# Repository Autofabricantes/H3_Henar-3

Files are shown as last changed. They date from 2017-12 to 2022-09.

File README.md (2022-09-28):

Hi! Welcome to the **_Henar#3 Wiki_**, please read carefully this welcome page that describes the full content of the _Wiki_.

This repository is still under construction (after many months, I know :'( ) Please if whatever doubt you have is not yet solved contact us somehow (email, Github, etc)

# Project Scope
The **_Henar#3_** is a _Open Source_ MIDI percussion instrument designed to perform live. Its main characteristics are:
* **Open Source:** The **_Henar#3_** has been designed and build with **_Open Source_** HW and SW and using accesible manufacturing technologies in order for it to be very affordable and easily moded.
* **Build Flexibility:** The **_Henar#3_** has been designed to allow a large number of different configurations (HMI elements in order to cope with the specific necessities of each user.
* **Stand Alone:** The **_Henar#3_** is an instrument designed to be played live, therefore it is a _Plug&Play_ device which does not need of extra elements to be played.
* **Pheriperic Flexibility:** Besides being a _Plug&Play_ device, the **_Henar#3_** allows its connection with other sound devices such as speakers and alternative MIDI devices.

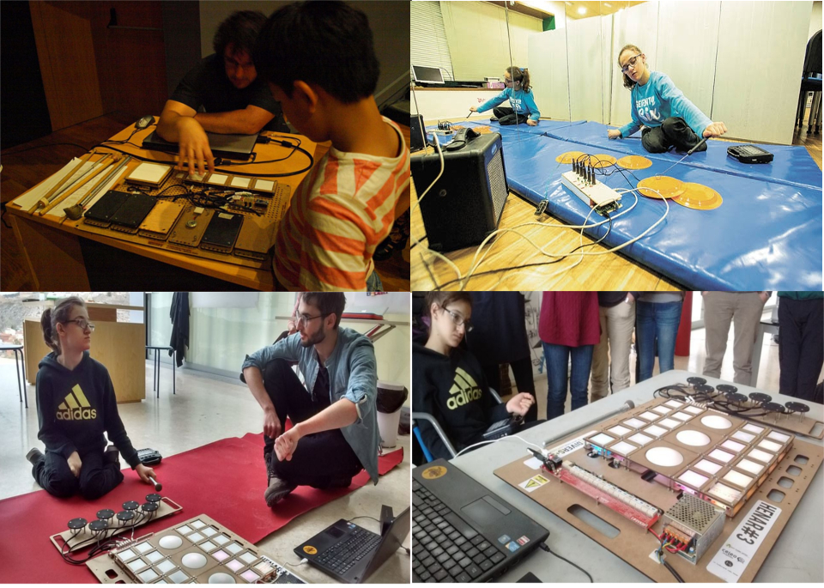
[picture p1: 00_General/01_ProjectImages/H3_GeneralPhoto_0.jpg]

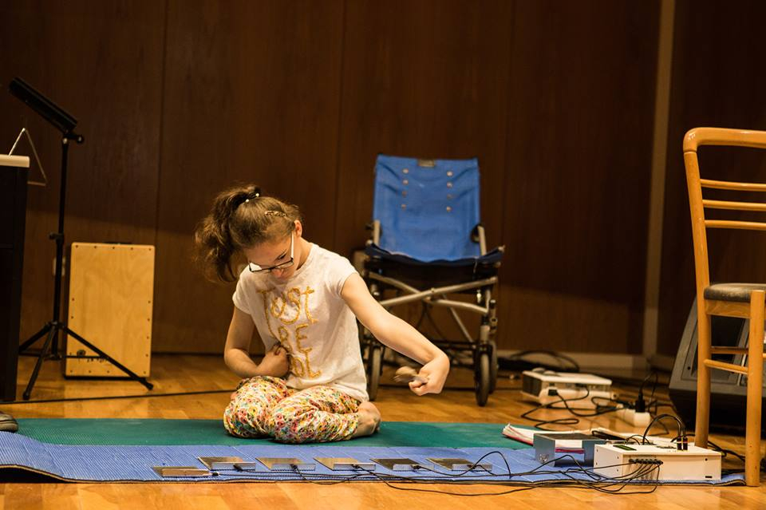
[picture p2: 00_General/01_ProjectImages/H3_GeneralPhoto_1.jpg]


# History and Collaborators
The **_Henar#3_** is part of a longer project started by the **_Celeo Proyectos_** and **_Un Instrumento para Henar_** in 2015. Its initial objective is to build a proper adapted instrument for Henar, a woman from Cuenca (Spain) that plays in an orchestra.

Apart from the instrument (which has two previous versions which will be described later) the project aims to build up a platform for the community of developers, users and enthusiasts to work together towards new ways to socialize with music and make it accesible for everyone. This is achieved not only though the development of the instrument itself but also through the creation of didactic materials and the organization of events such as **_DiverS+S 2017_** (http://www.diversos.eu/), where various projects were presented and put in common, in order to create links and an active net.

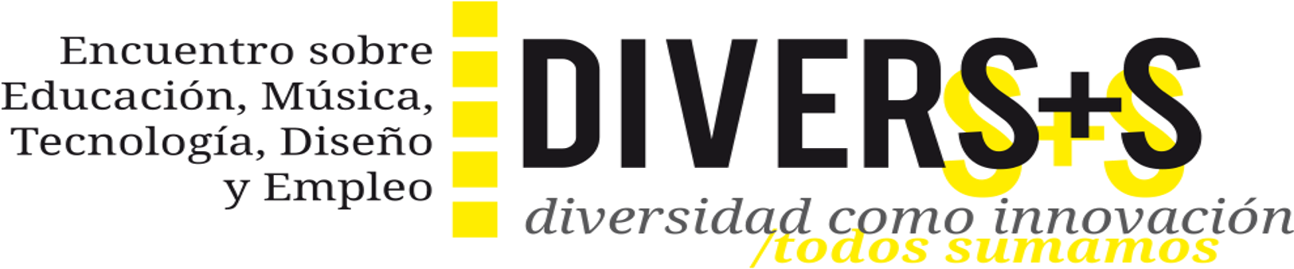
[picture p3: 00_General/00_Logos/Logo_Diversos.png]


The collaborators of this project are:
## Celeo Proyectos

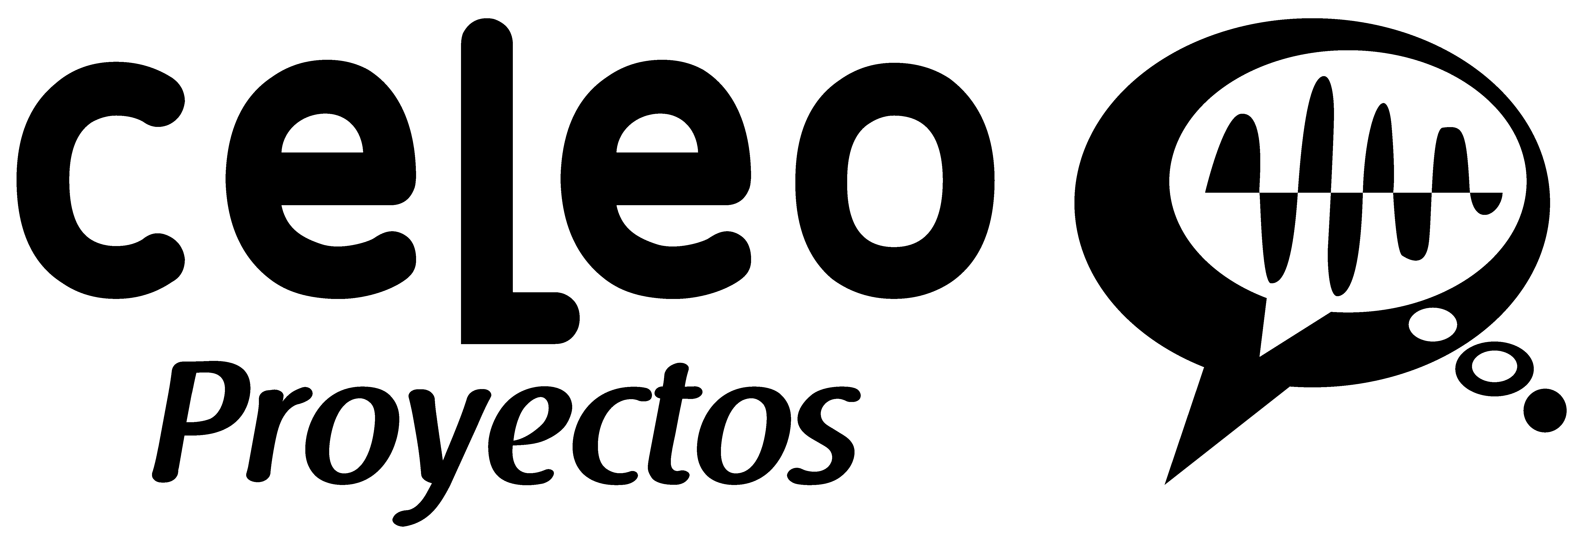
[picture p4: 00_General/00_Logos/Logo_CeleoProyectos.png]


## Un instrumento para Henar



### Website: www.centroceleo.es/henar
### Contact: uninstrumentoparahenar@gmail.com

## Autofabricantes
**_Autofabricantes_** in an association based in _Medialab-Prado_, Madrid. It develops several _Open Source_ technological solutions in the medical and accesibility field. It's main development lines right now are:
* Myoelectric Hand Prothesis for children.
* 3D printed hand prosthesis for children (both experimental like __SuperGizz__ and standard).
* **_Henar#3_** instrument (The one this Wiki covers).

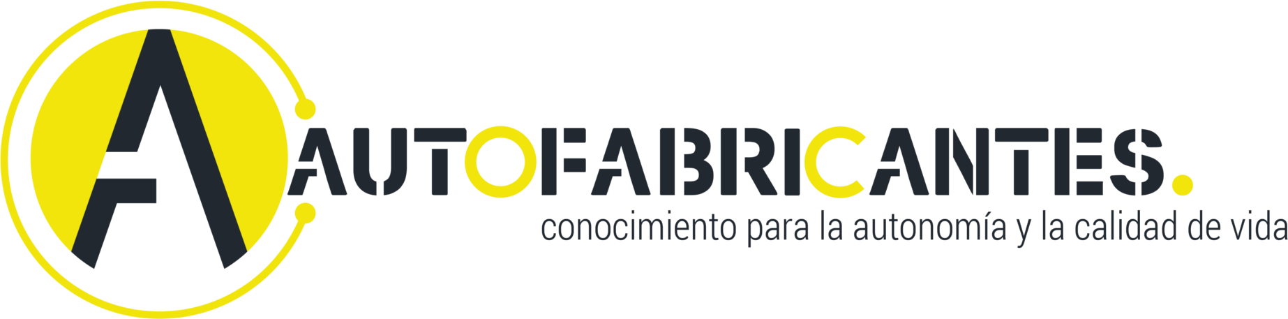
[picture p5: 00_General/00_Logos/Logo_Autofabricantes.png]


### Website: www.autofabricantes.org
### Contact: info@autofabricantes.org

## Escuela de Oficios Electrosonoros
_**Escuela de Oficios Electrosonoros**_ (in eng. _**School for Electrosonic Crafts**_) is an artistic and educational project that works to make electronic music (or music made with technology in general) accesible to everyone. 

*  Elaborate a feministic (or better just... diverse) history of electronic music.
*  Develop pedagogical tools for teaching electronic music in schools.
*  Research about accessibility of electronic music.

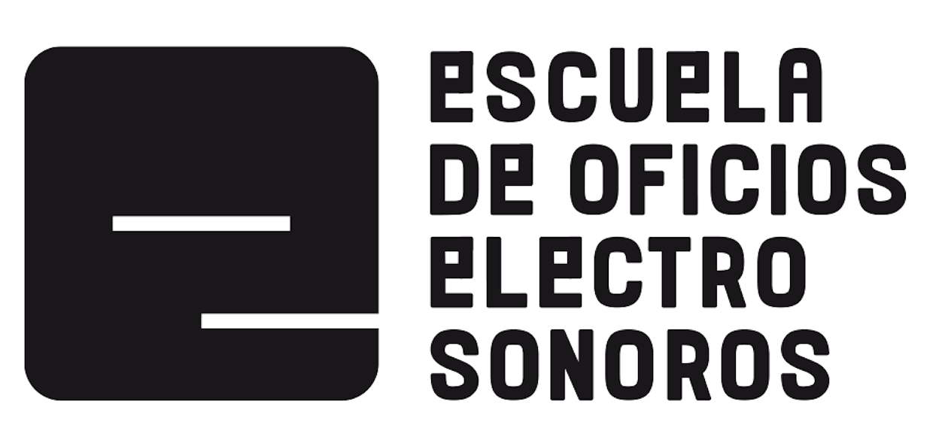
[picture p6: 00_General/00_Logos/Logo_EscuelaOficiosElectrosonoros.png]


### Website: www.oficioselectrosonoros.org
### Contact: gurrupibaby@gmail.com

# About the previous Henar (Henar#1, Henar#2)
The Un instrumento para Henar project has already developed two previous versions of the instruments.

## Henar#1: [HERE LINK]
## Henar#2: [HERE LINK]

The **_Henar#3_** improvement objetives are:
* Increase System flexibility.
* Easier Assembly and manufacturing.
* Easier MIDI configuration.
* Improved ergonomy.

# Scope of the Wiki
This _Wiki_ aims to concentrate all the knowledge of the project. This covers:
* Global description of the project and its subsystems.
* Description of all the files in the repository.
* Description of all the elements and their evolution.
* **Assembly Guide** of all the elements (HW, SW, Mechanical).
* Tutorials and other didactic material.

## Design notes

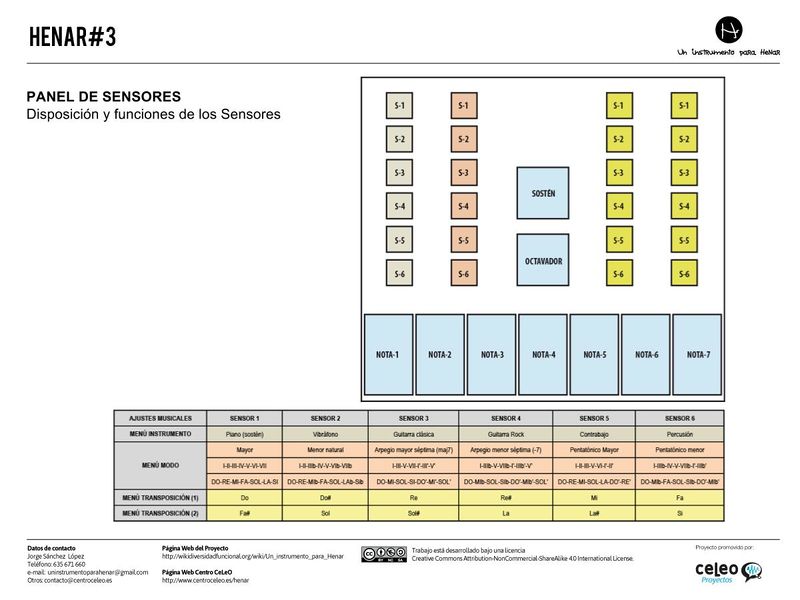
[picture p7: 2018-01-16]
01_Documentation/H3_ControlPanelProposal.jpg

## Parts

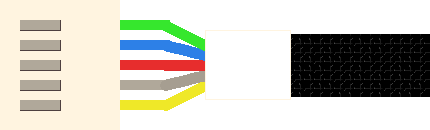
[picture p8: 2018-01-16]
03_Resources/H3_ComponentImages/H3_Wire_SWPad_Rev_1_2DRender_Simple.png

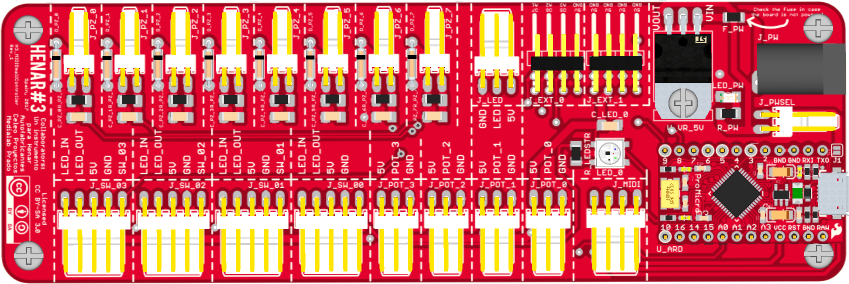
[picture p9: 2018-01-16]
03_Resources/H3_ComponentImages/H3_MIDISmallController_Rev_1_2DRender_A.png

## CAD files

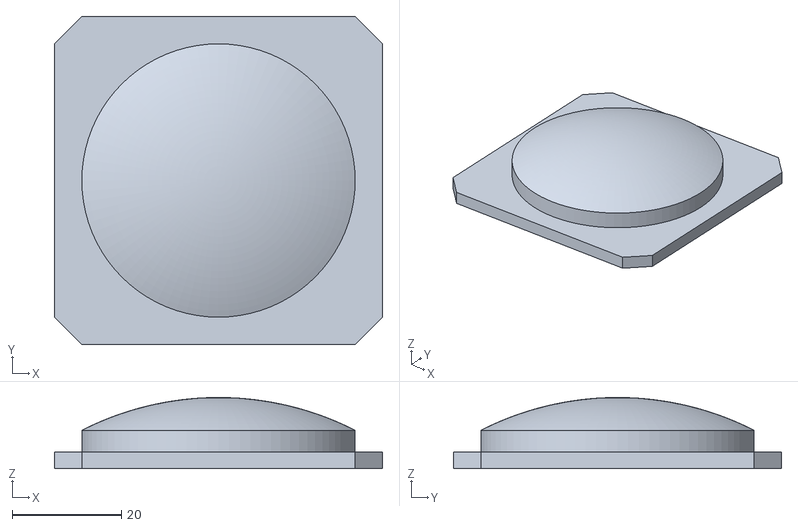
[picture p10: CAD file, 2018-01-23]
02_Elements/H3_SWPad_Big_Rev_3/03_Mechanics/H3_SWPad_Small_Rev_3_PadPiece_Circle.stl
60.0 x 60.0 x 13.0

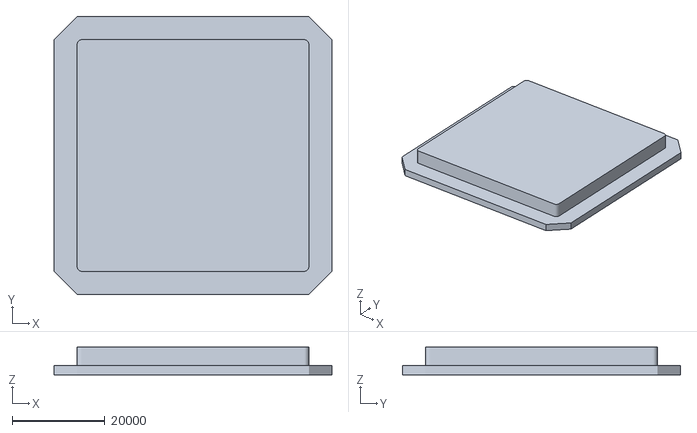
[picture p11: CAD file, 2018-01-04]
02_Elements/H3_SWPad_Small_Rev_3/01_HW/eagleUp/HW_SWPad_Small_Rev_3_PadPiece_A.stl
60000.0 x 60000.0 x 6000.0

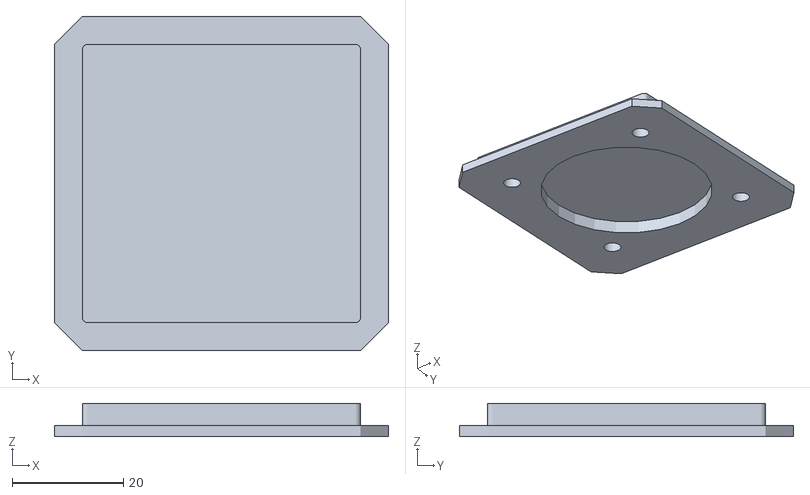
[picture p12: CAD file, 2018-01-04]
02_Elements/H3_SWPad_Big_Rev_3/03_Mechanics/H3_SWPad_Small_Rev_3_PadPiece_Square.stl
60.0 x 60.0 x 6.00

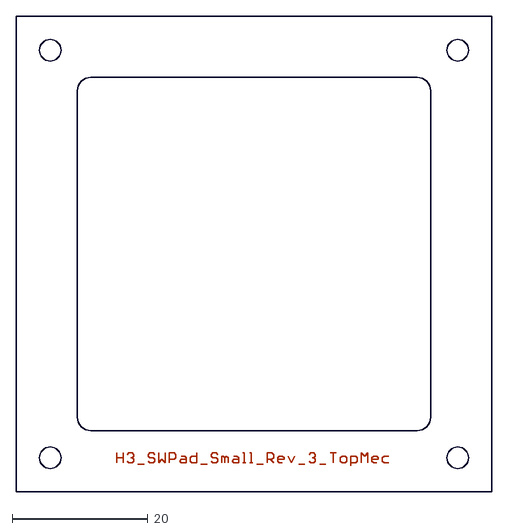
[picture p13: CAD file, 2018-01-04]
02_Elements/H3_SWPad_Big_Rev_3/03_Mechanics/H3_SWPad_Small_Rev_3_TopMec.dxf
70.0 x 70.0

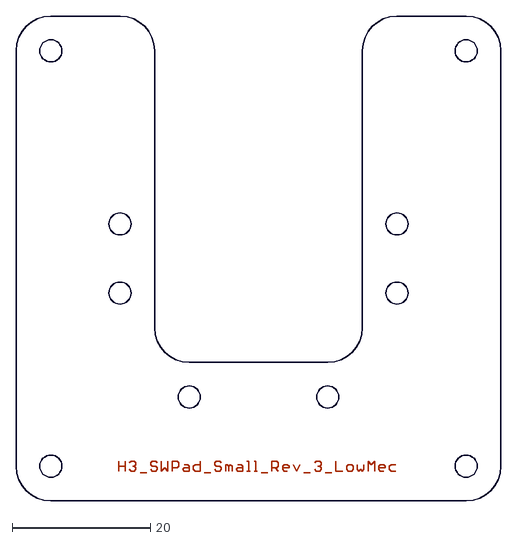
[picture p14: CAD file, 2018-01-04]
02_Elements/H3_SWPad_Big_Rev_3/03_Mechanics/H3_SWPad_Small_Rev_3_BotMec.dxf
70.0 x 70.0

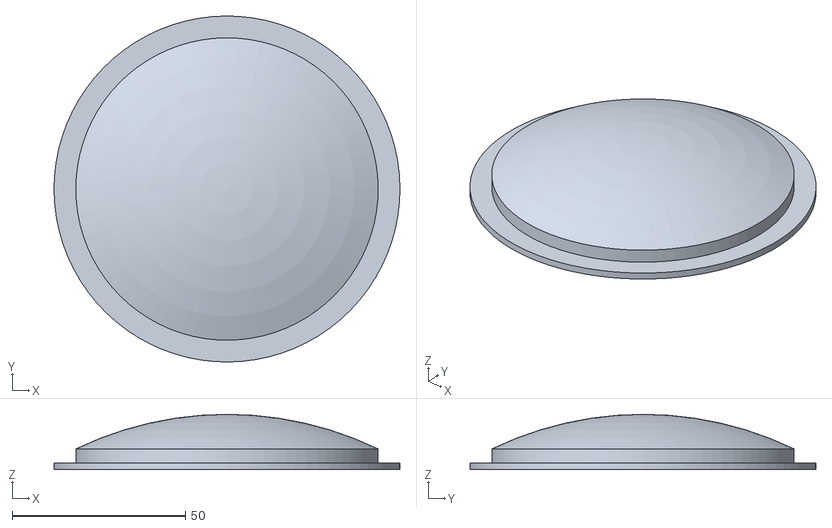
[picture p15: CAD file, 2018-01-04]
02_Elements/H3_SWPad_Big_Rev_3/03_Mechanics/H3_SWPad_Big_Rev_3_PadPiece_Circle.stl
100.0 x 100.0 x 16.0

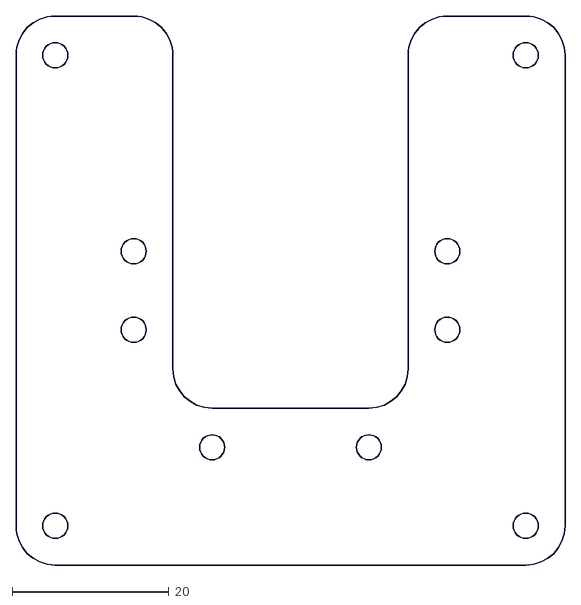
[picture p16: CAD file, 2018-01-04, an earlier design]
02_Elements/H3_SWPad_Small_Rev_2/03_Mechanics/H3_SWPad_Small_Rev_2_BotMec.dxf
70.0 x 70.0

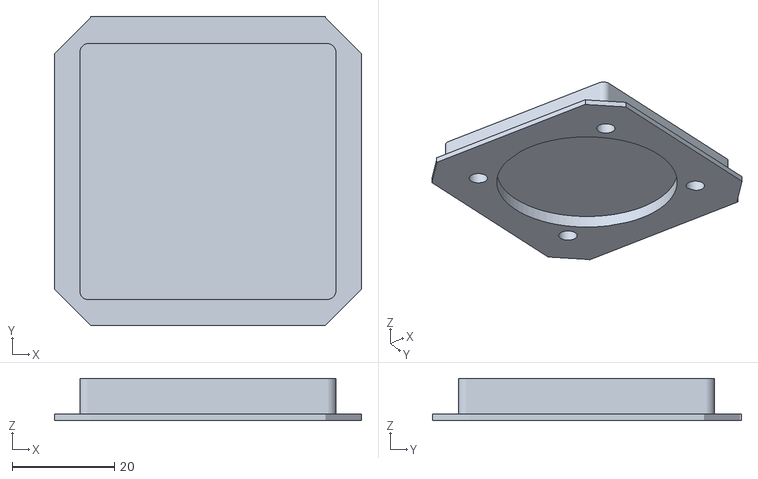
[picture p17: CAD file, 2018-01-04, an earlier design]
02_Elements/H3_SWPad_Small_Rev_2/03_Mechanics/H3_SWPad_Small_Rev_2_Pad_Square_Simple7mm.stl
60.0 x 60.4 x 8.30

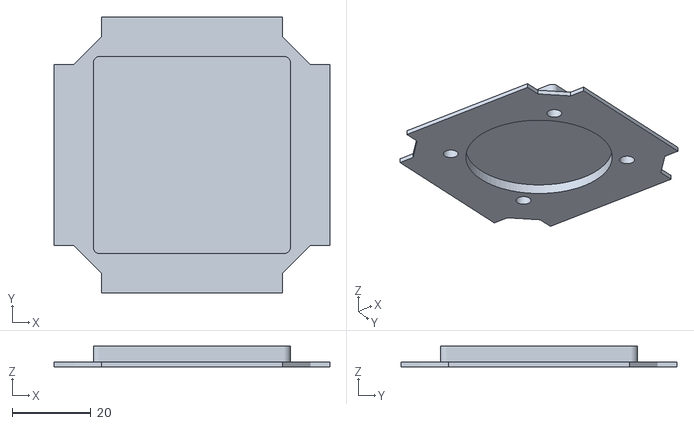
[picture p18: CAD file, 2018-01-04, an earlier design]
02_Elements/H3_SWPad_Small_Rev_2/03_Mechanics/H3_SWPad_Small_Rev_2_Pad_Square_Simple.stl
70.0 x 70.0 x 5.30

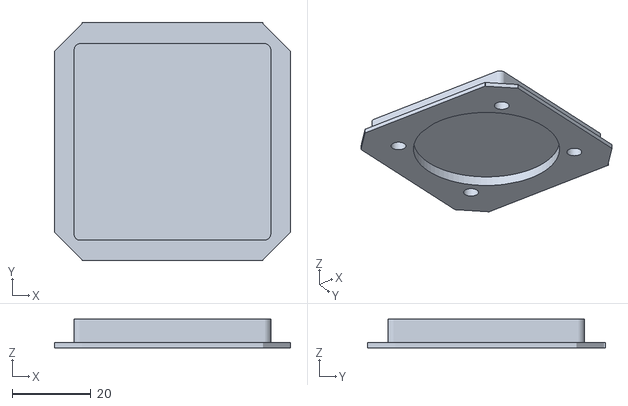
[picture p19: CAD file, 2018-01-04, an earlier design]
02_Elements/H3_SWPad_Small_Rev_2/03_Mechanics/H3_SWPad_Small_Rev_2_Pad_Square_Simple6mm.stl
60.0 x 60.4 x 7.30

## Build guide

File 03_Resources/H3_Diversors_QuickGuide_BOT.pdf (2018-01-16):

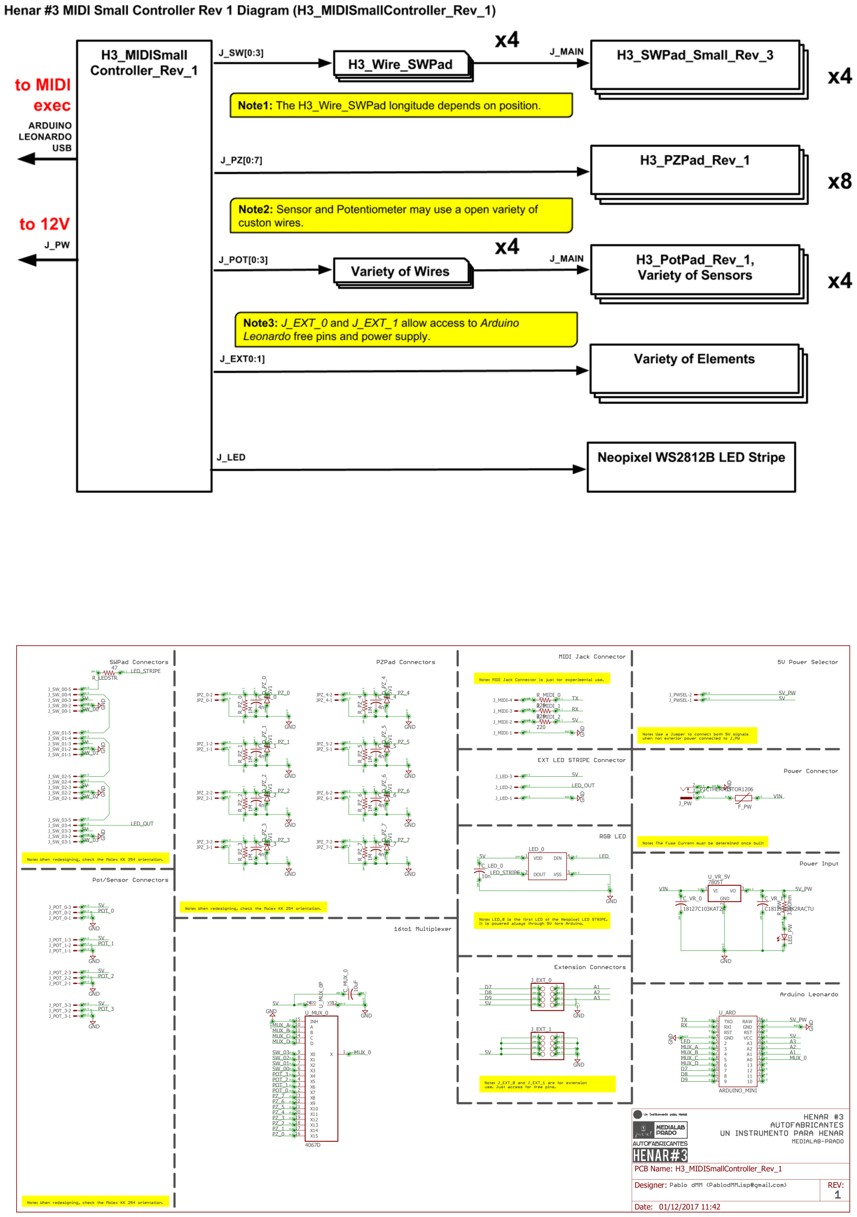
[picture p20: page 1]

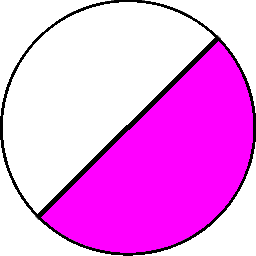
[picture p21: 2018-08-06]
01_Documentation/H3_GuideResources/H3_PAD_Render/H3_PAD_VSWAP_ON.png

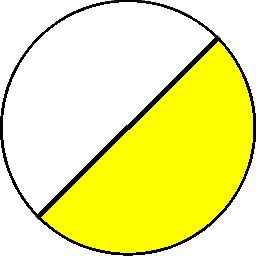
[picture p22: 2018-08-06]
01_Documentation/H3_GuideResources/H3_PAD_Render/H3_PAD_CHORD_ON.png

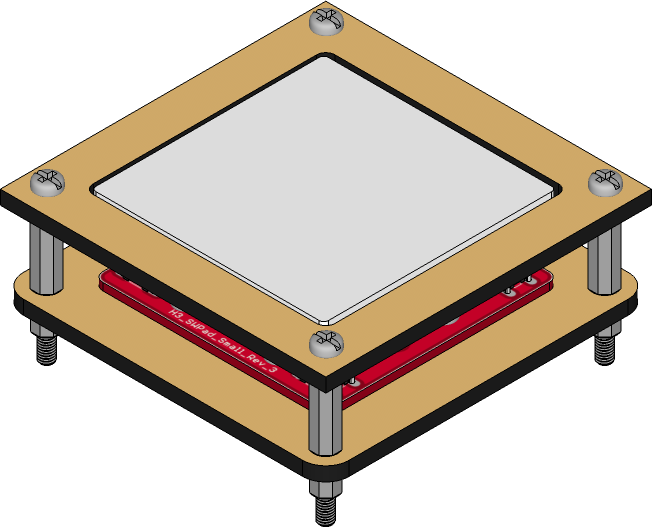
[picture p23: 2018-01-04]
02_Elements/H3_SWPad_Big_Rev_3/00_Documentation/H3_SWPad_Small_Rev_3_Assembled_2DRender.png

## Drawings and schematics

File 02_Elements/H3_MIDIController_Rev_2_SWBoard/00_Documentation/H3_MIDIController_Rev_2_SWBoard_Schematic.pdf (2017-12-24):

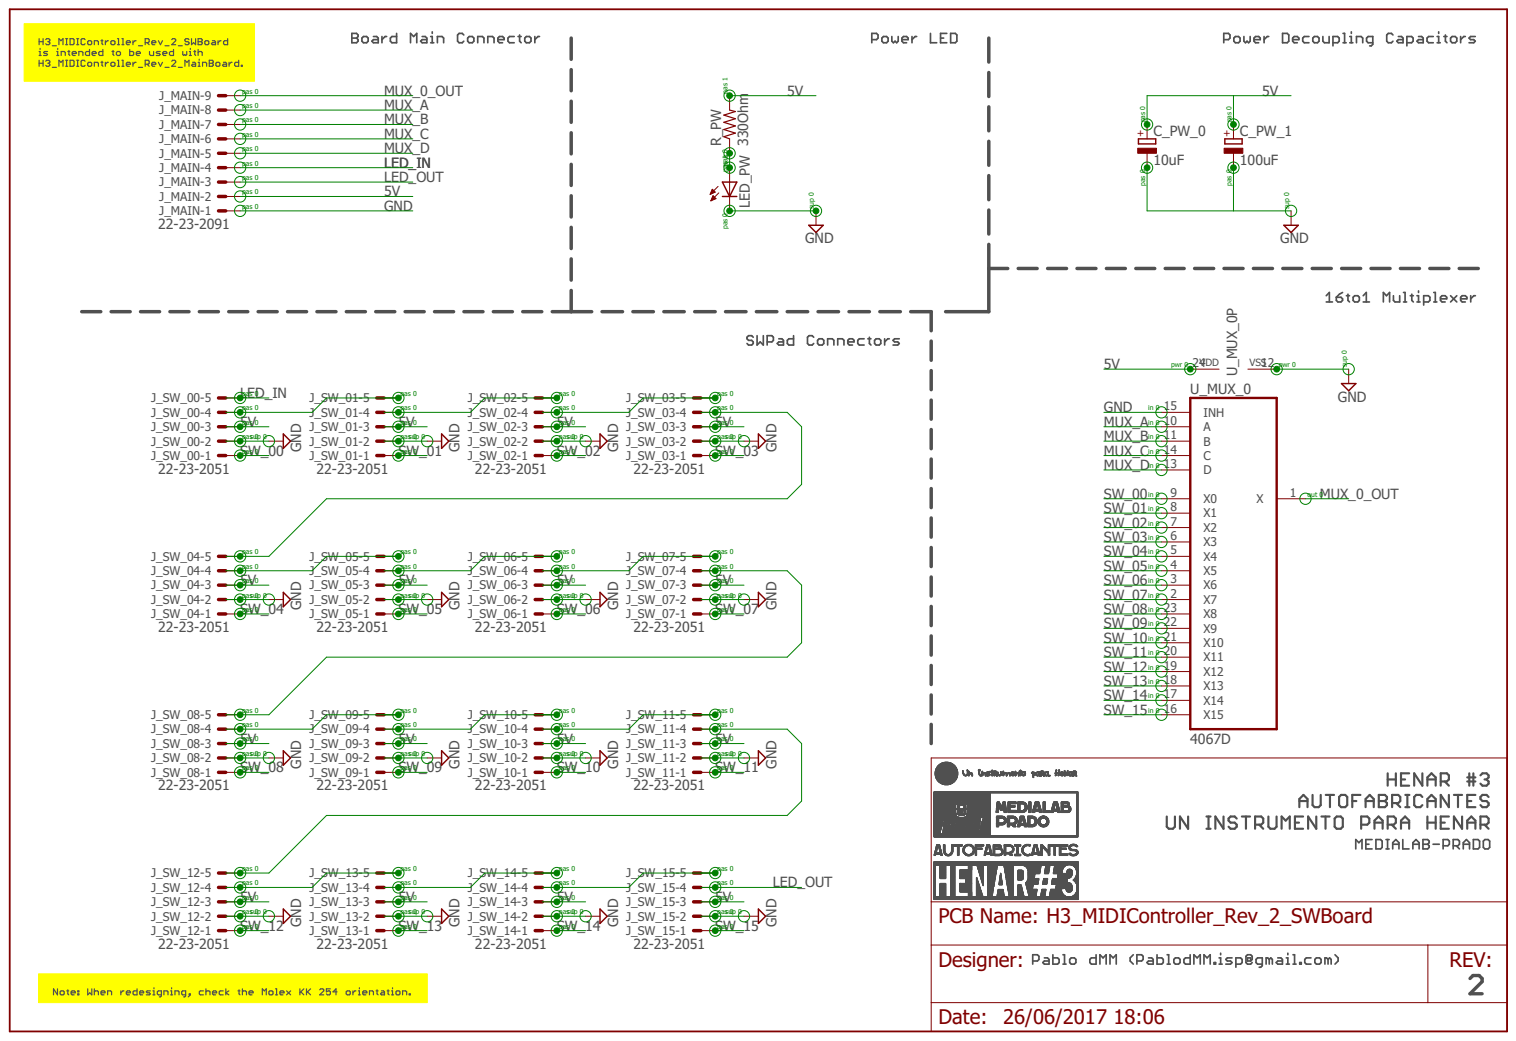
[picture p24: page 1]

pas 0 pas 0 pas 1 pas 1

pas 0 pas 0 pas 0 pas 0 pas 0 pas 0 pas 0 pas 0 pas 0

LED_IN
pas 0 pas 0 pas 0 pas 0 pas 0

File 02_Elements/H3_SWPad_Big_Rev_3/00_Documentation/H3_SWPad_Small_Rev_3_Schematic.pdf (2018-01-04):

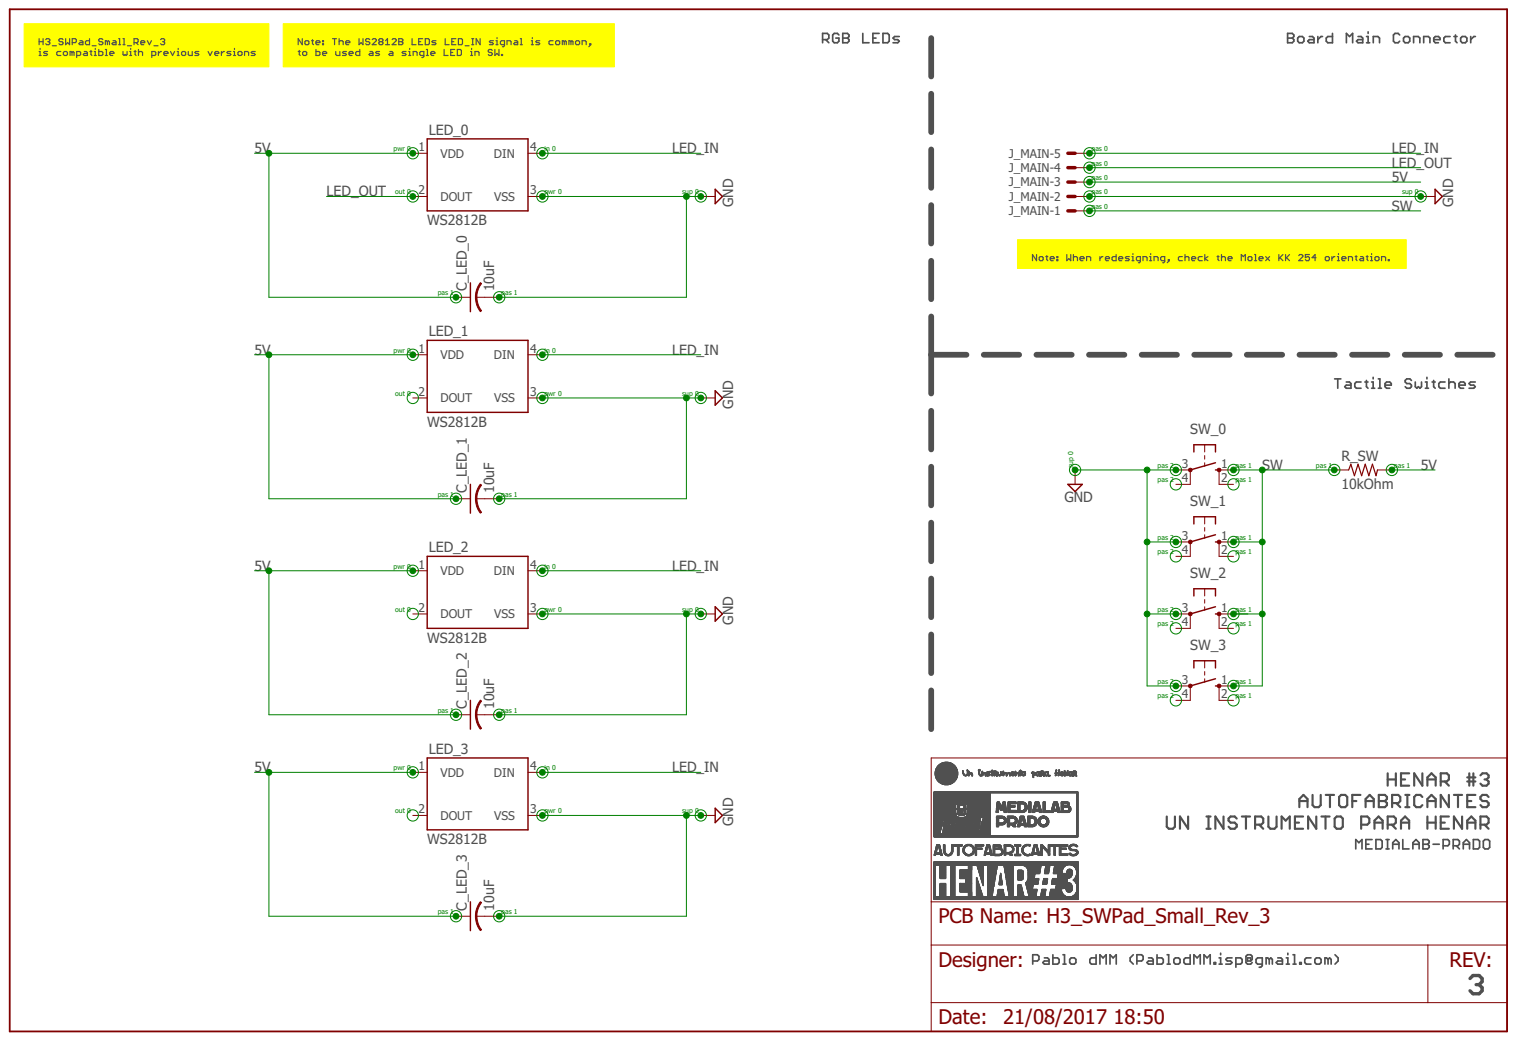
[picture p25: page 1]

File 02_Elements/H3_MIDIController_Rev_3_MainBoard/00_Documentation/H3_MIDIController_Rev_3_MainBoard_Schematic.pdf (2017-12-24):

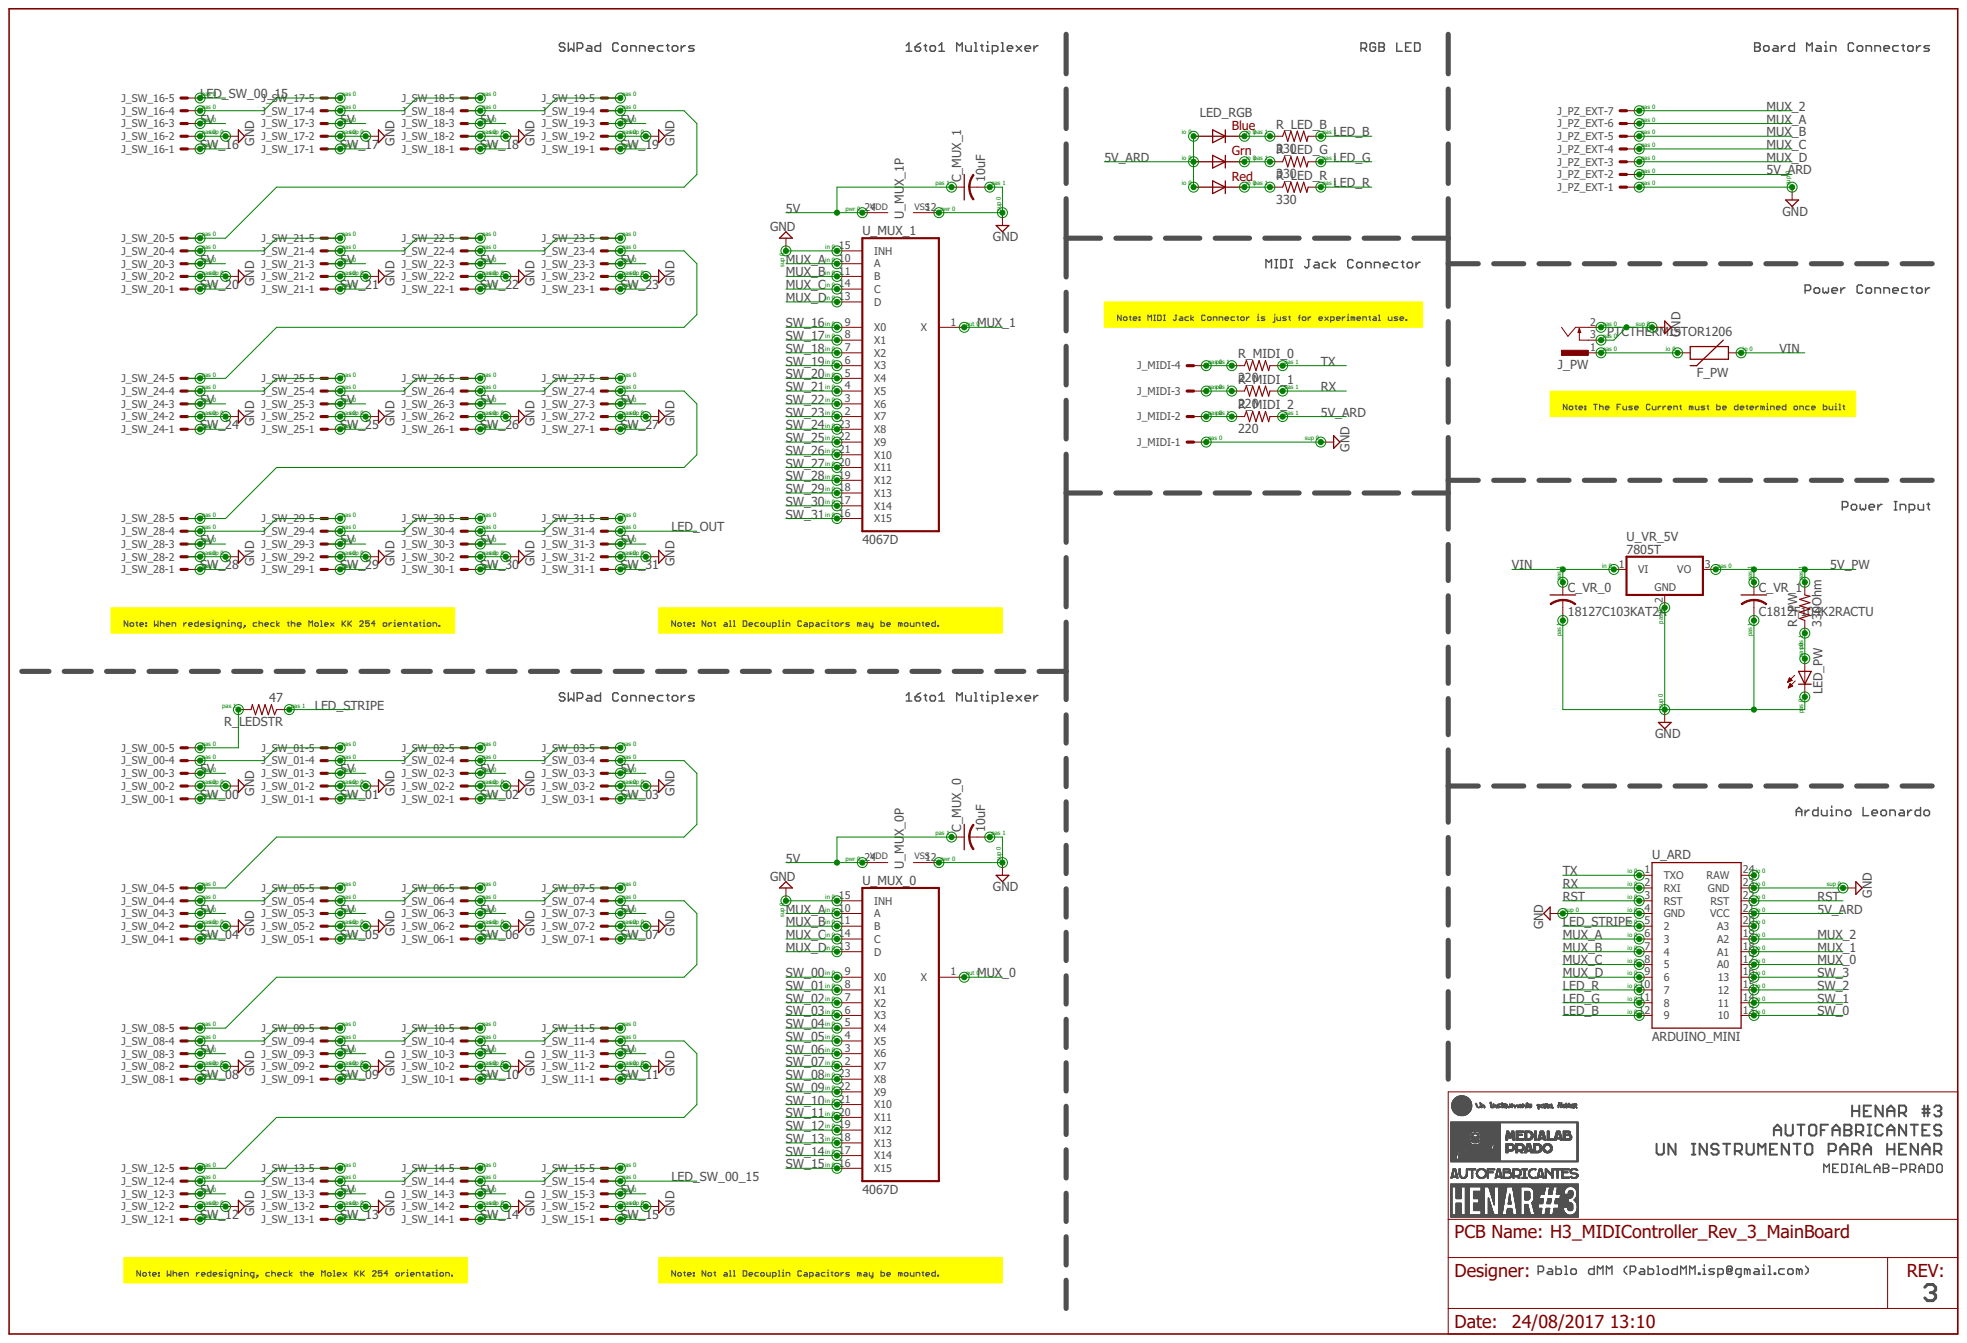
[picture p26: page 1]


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

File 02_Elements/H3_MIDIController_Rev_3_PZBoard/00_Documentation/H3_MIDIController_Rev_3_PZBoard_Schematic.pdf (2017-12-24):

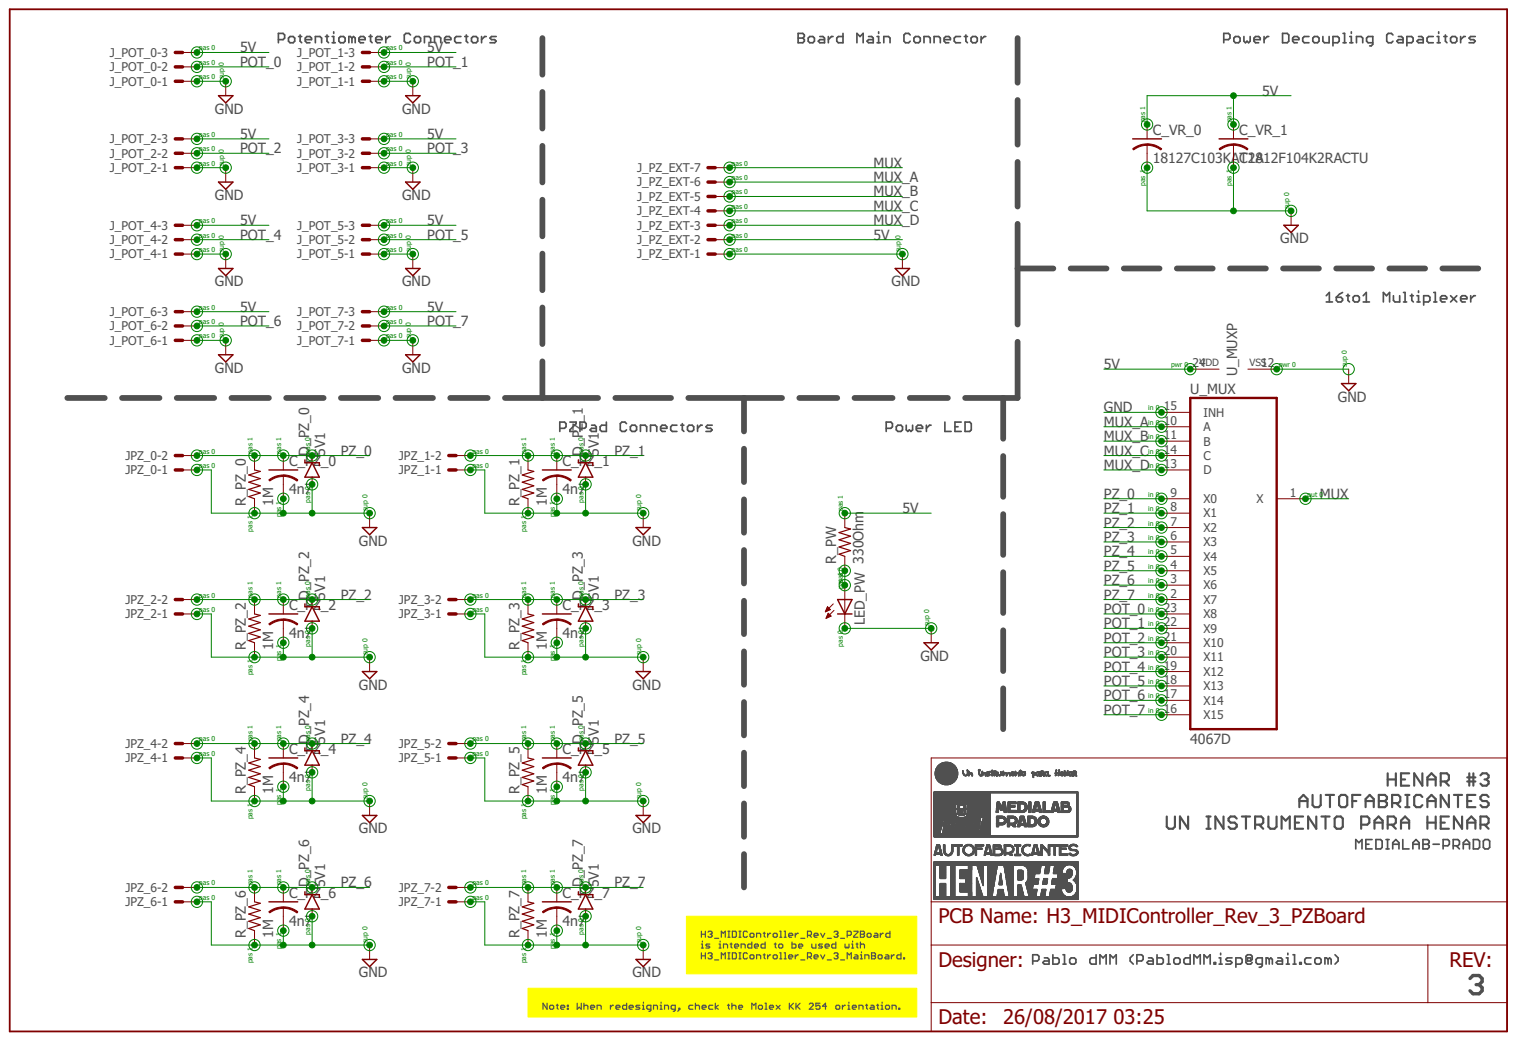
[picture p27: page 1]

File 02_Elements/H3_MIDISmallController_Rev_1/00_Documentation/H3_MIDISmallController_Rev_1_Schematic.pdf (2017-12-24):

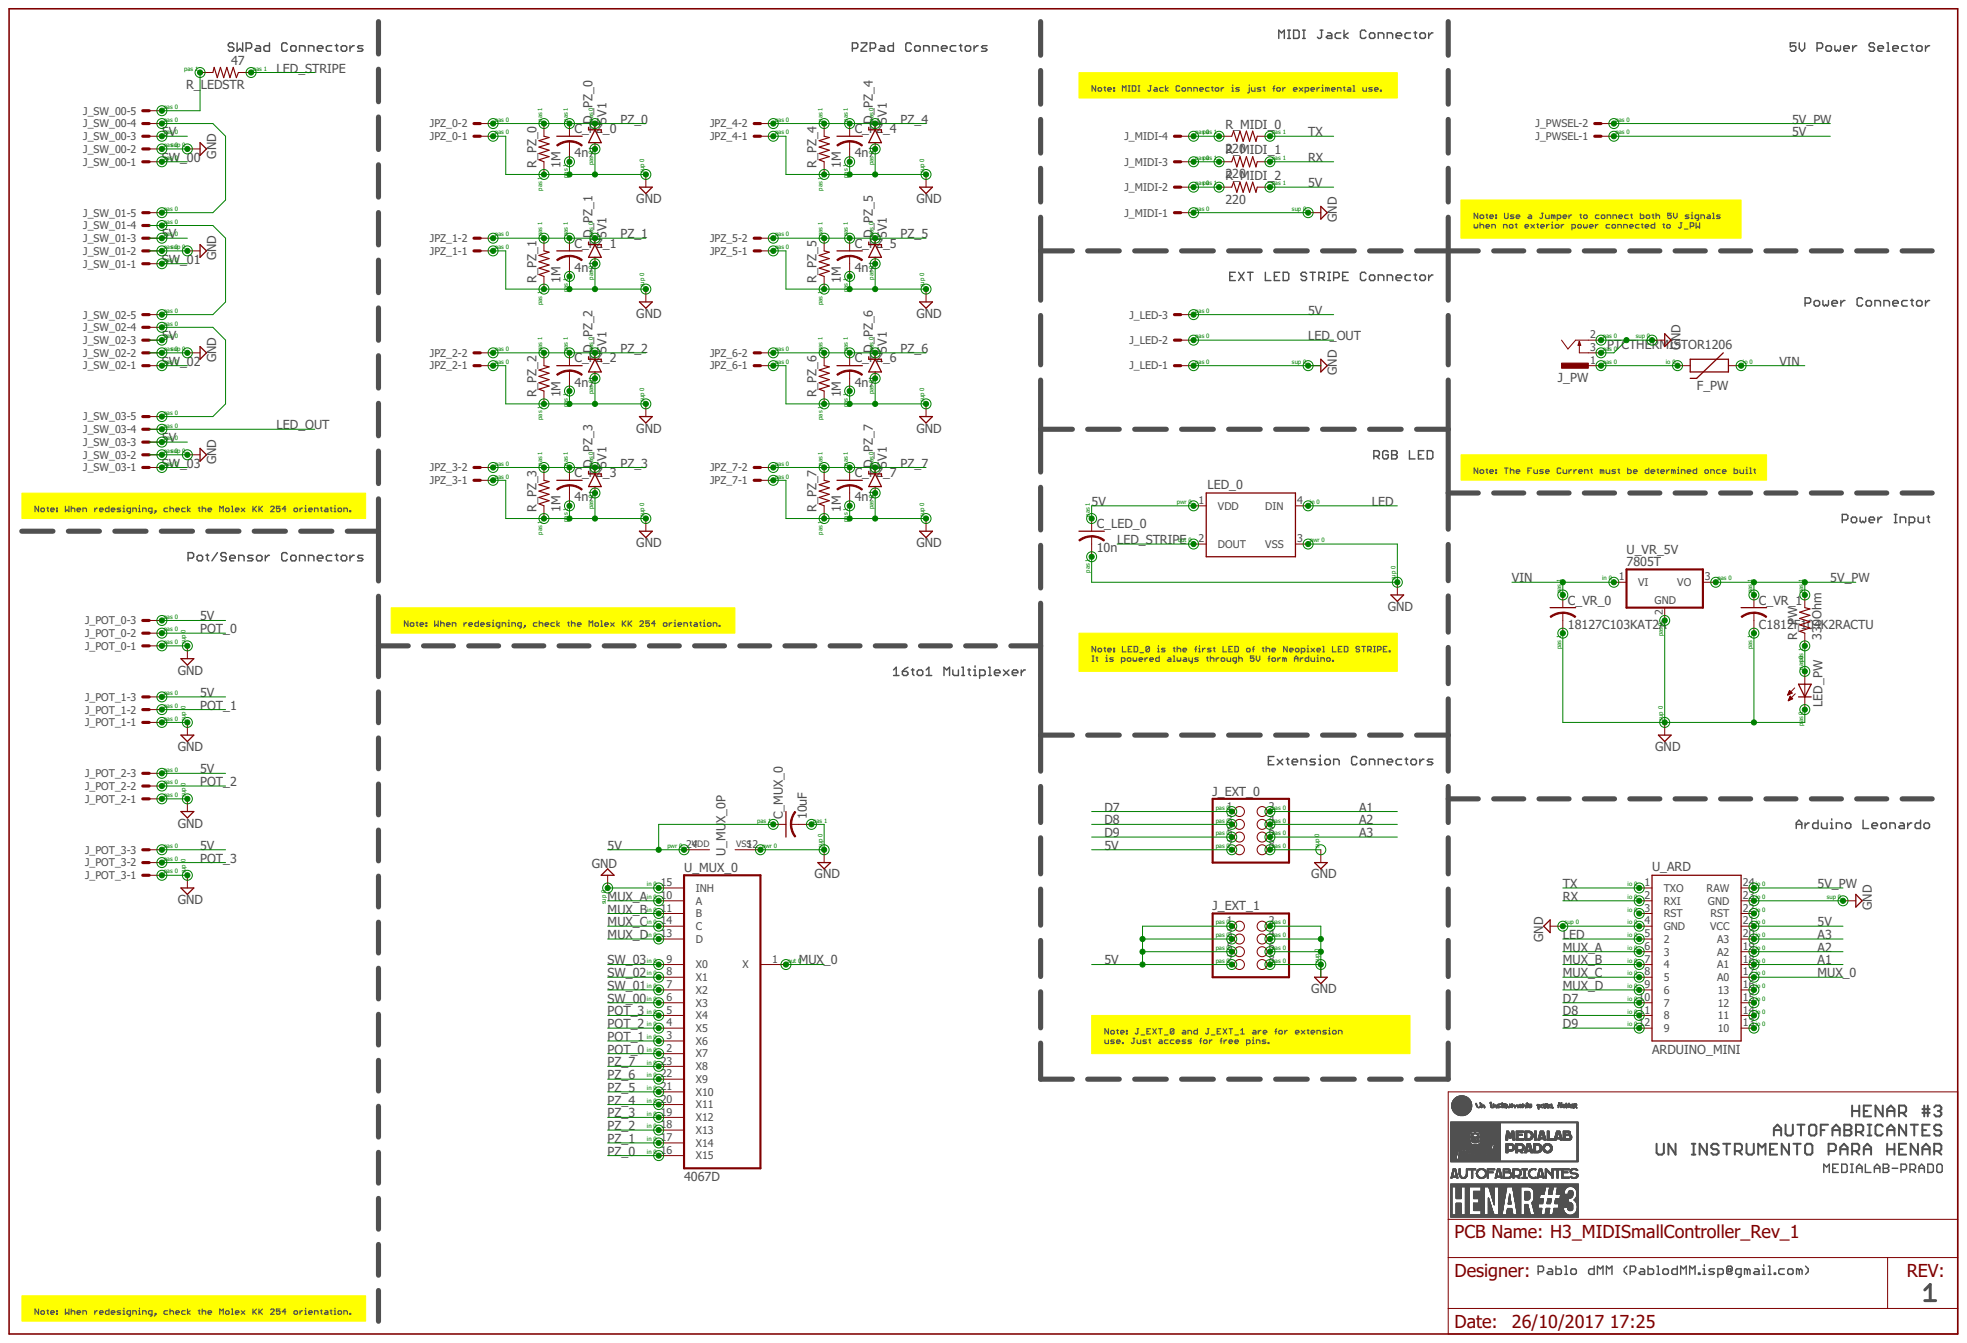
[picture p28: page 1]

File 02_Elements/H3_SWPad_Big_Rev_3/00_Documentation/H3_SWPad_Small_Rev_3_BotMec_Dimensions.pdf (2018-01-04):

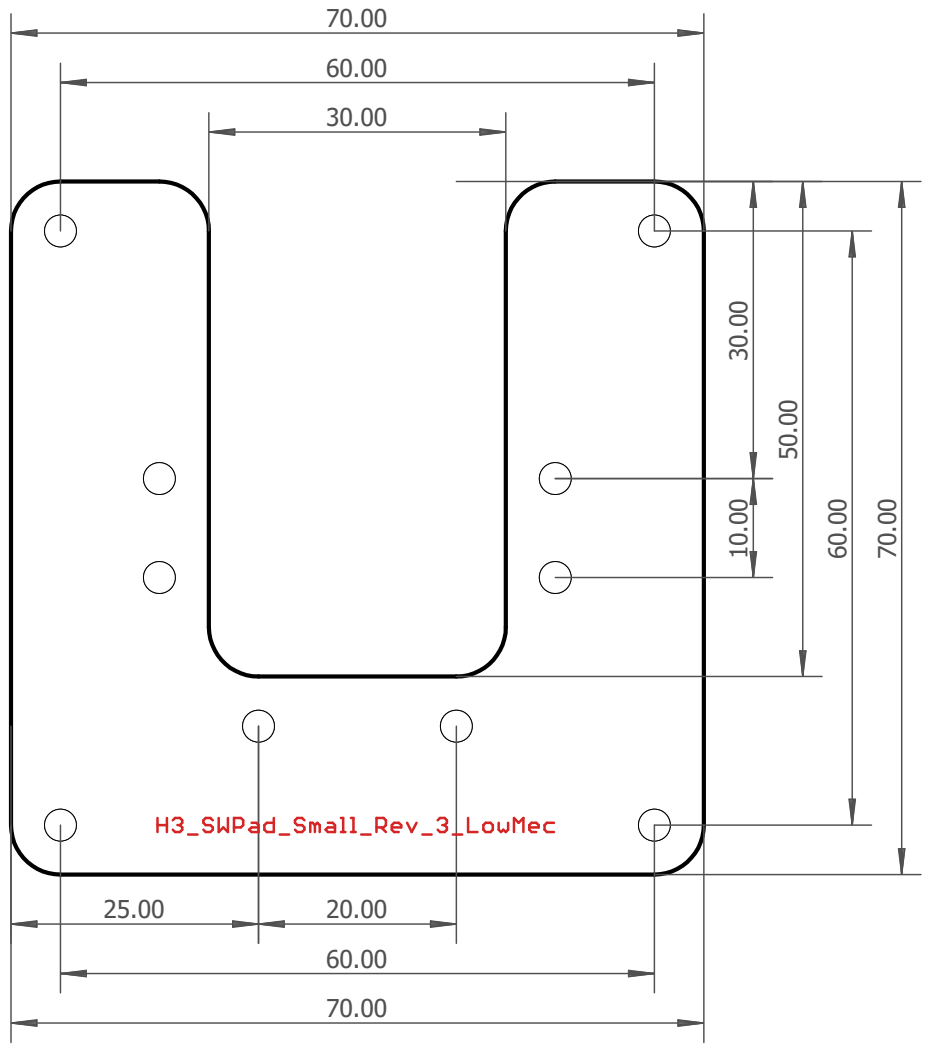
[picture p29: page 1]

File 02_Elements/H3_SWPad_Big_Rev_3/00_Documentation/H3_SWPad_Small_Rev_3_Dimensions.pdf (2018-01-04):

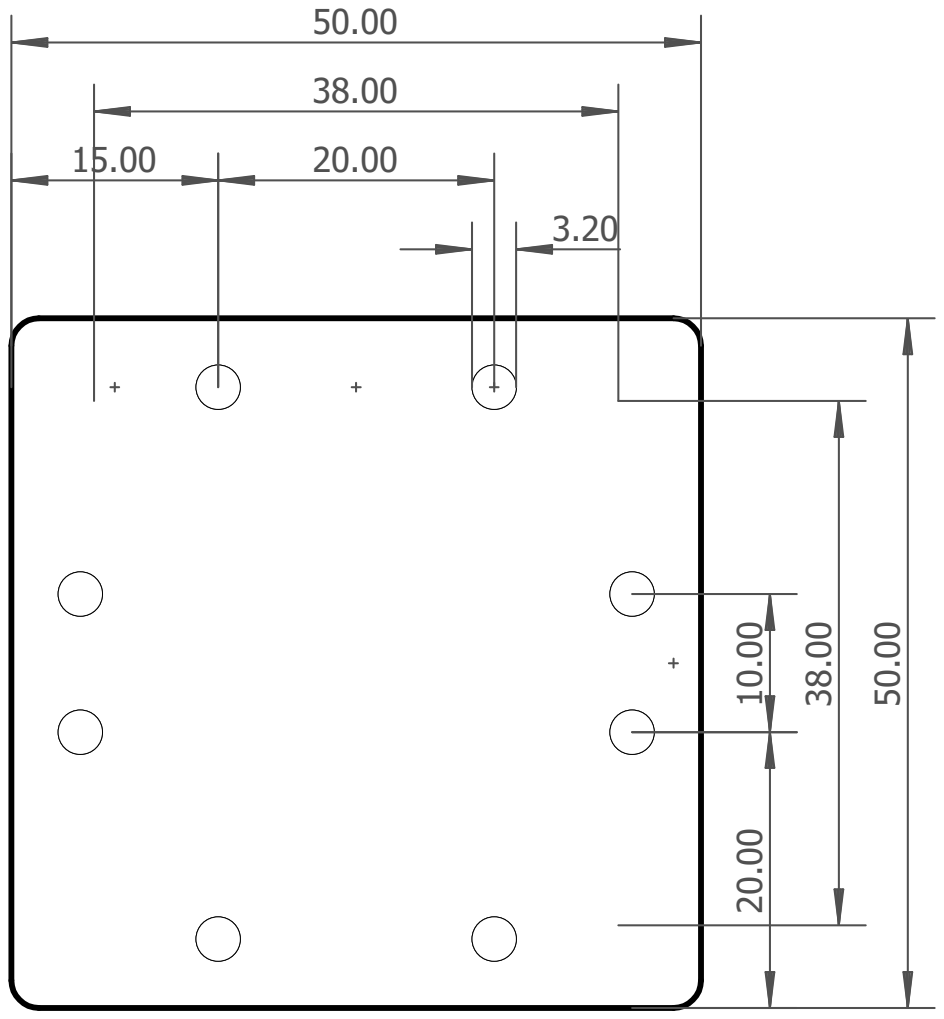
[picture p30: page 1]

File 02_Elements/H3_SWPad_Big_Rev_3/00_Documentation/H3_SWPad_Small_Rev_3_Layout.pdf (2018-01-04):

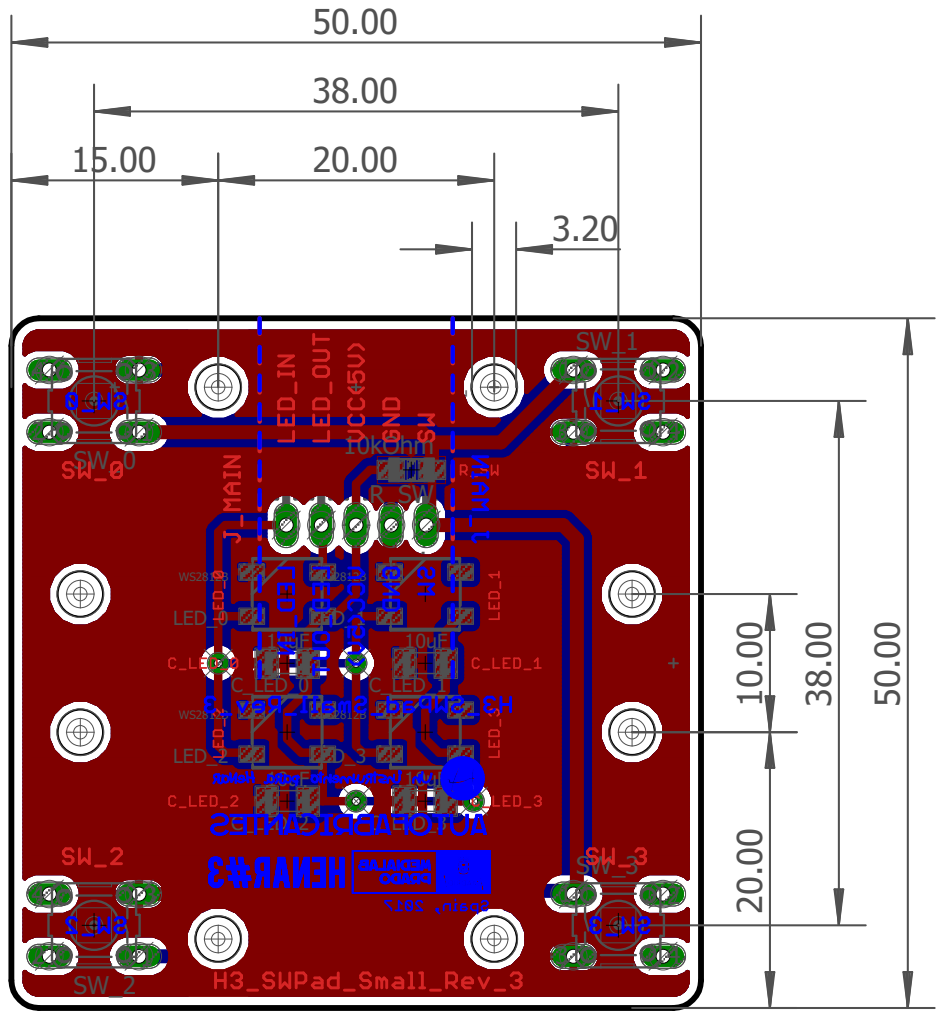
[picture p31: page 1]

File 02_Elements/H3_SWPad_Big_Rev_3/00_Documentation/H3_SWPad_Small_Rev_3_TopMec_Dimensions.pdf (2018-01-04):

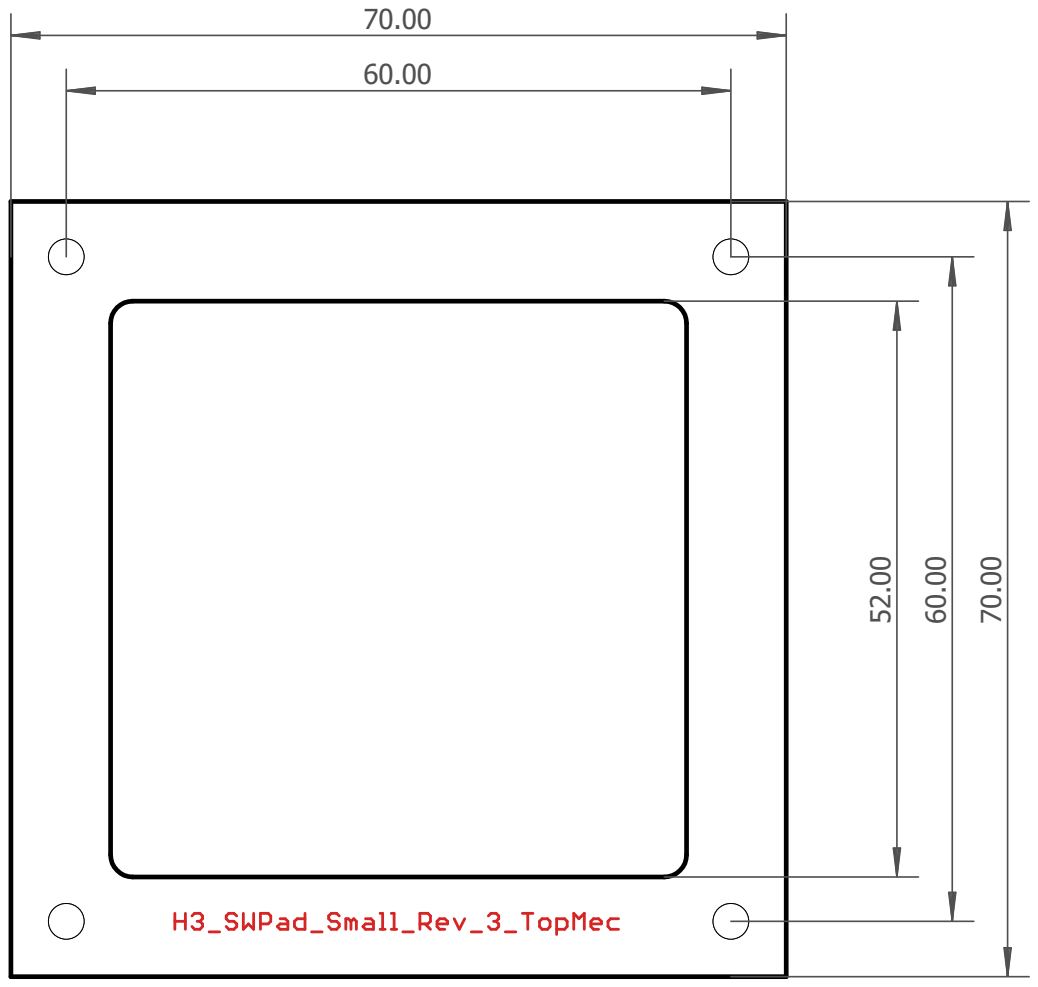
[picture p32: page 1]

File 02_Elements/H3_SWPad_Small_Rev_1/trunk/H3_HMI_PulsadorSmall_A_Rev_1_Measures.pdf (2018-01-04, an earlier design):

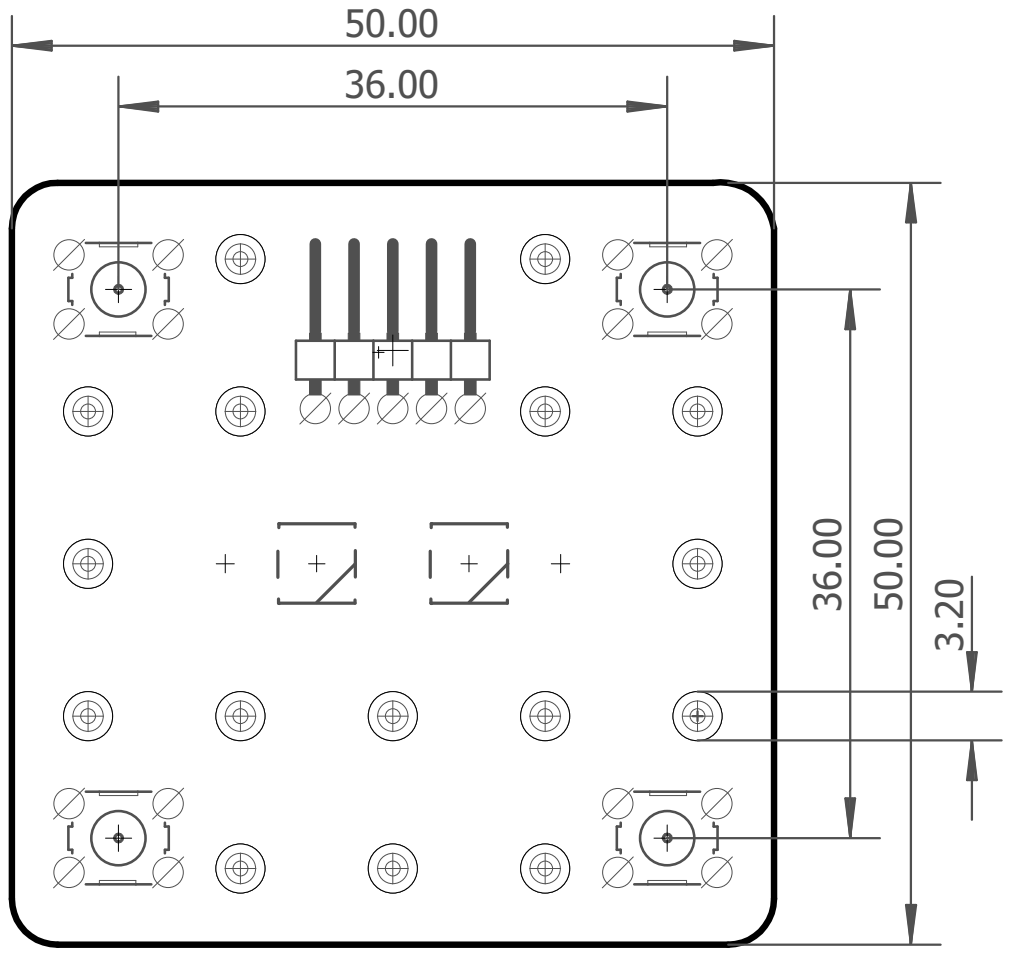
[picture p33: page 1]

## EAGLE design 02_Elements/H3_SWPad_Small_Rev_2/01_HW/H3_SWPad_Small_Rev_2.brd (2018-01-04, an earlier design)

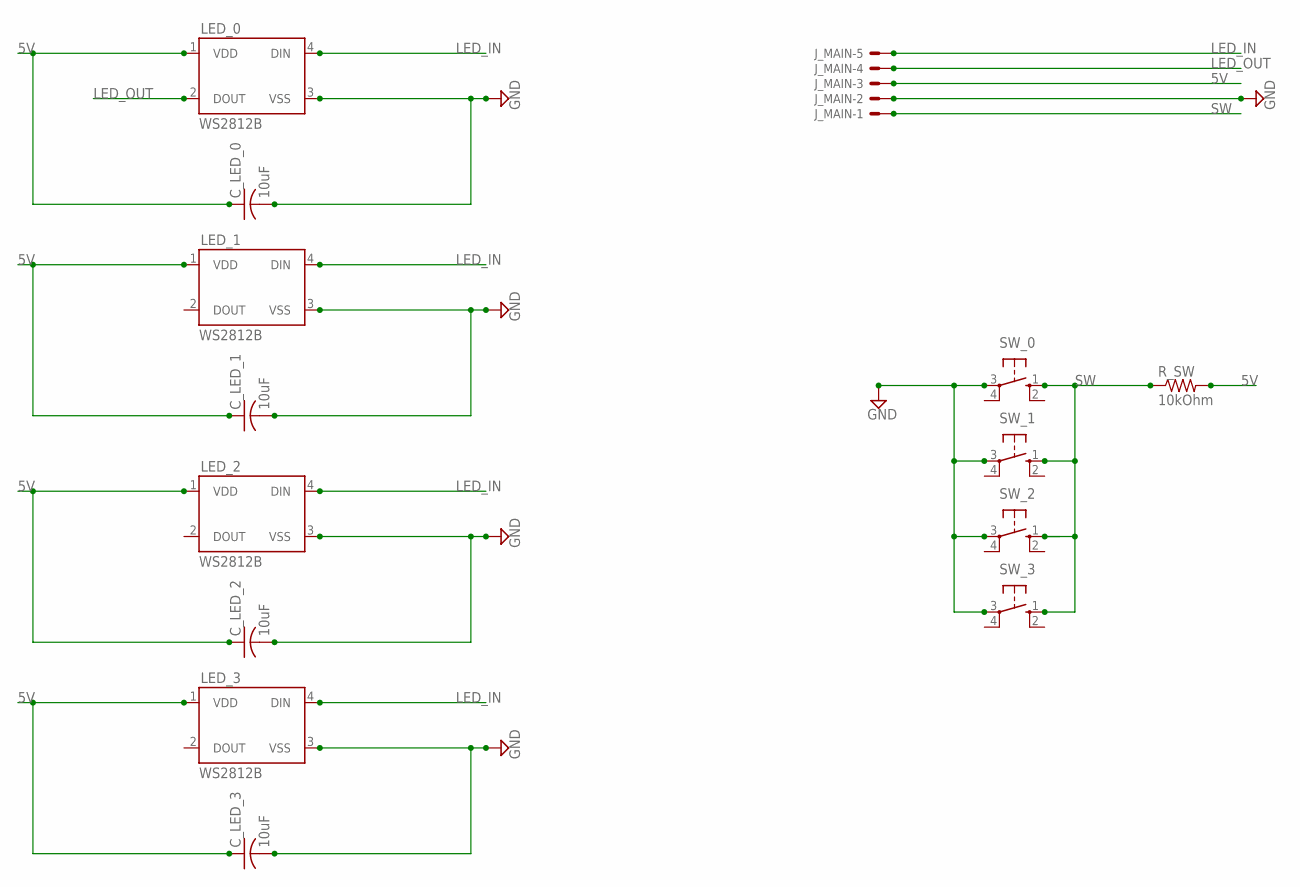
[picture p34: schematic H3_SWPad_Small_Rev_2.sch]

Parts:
C_LED_0, C_LED_1, C_LED_2, C_LED_3: 10uF; C1206K
J_MAIN: 22-05-7058-05; 7395-05
LED_0, LED_1, LED_2, LED_3: WS2812B
R_SW: 10kOhm; R1206W
SW_0, SW_1, SW_2, SW_3: 10-XX; B3F-10XX

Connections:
5V: C_LED_0.1, C_LED_1.1, C_LED_2.1, C_LED_3.1, J_MAIN.3, LED_0.1 (VDD), LED_1.1 (VDD), LED_2.1 (VDD), LED_3.1 (VDD), R_SW.2
GND: C_LED_0.2, C_LED_1.2, C_LED_2.2, C_LED_3.2, J_MAIN.2, LED_0.3 (VSS), LED_1.3 (VSS), LED_2.3 (VSS), LED_3.3 (VSS), SW_0.3, SW_1.3, SW_2.3, SW_3.3
LED_IN: J_MAIN.5, LED_0.4 (DIN), LED_1.4 (DIN), LED_2.4 (DIN), LED_3.4 (DIN)
LED_OUT: J_MAIN.4, LED_0.2 (DOUT)
SW: J_MAIN.1, R_SW.1, SW_0.1 (S), SW_1.1 (S), SW_2.1 (S), SW_3.1 (S)

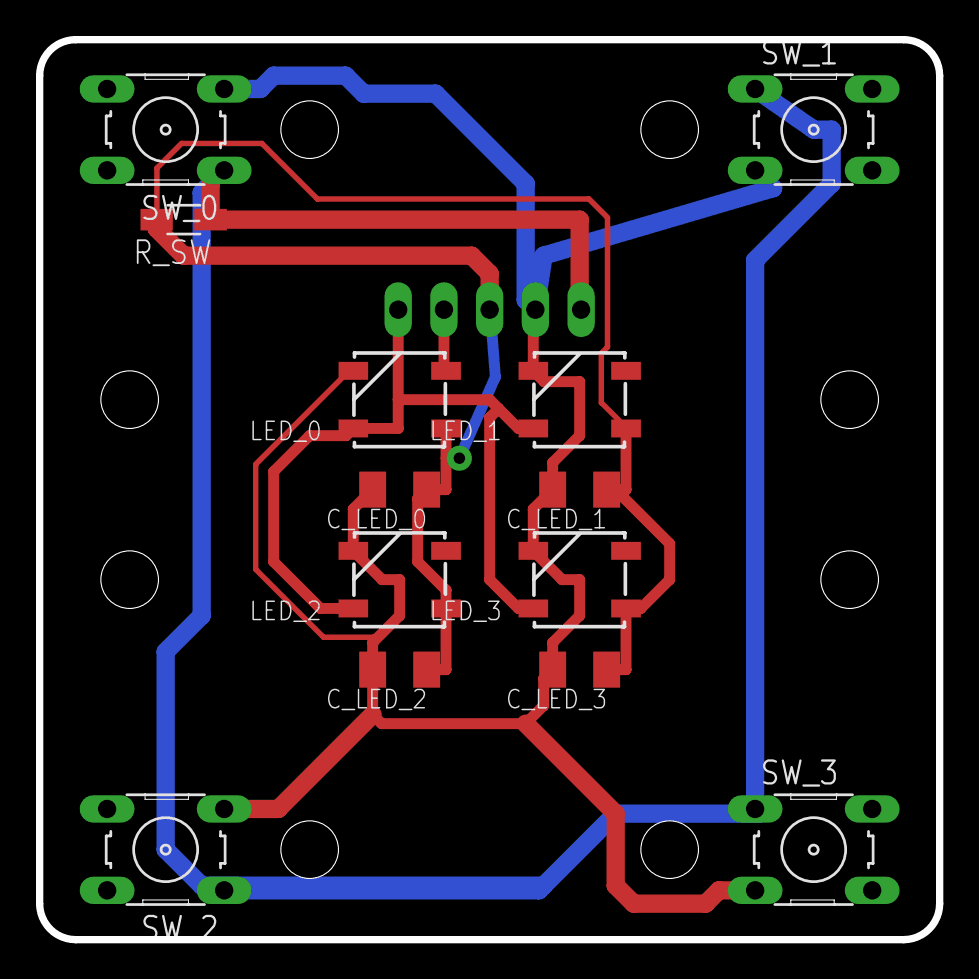
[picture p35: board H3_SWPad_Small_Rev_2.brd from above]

Board: 2 copper layers, 50.0 x 50.0 mm, 14 parts (1 on the bottom side), 5 nets.

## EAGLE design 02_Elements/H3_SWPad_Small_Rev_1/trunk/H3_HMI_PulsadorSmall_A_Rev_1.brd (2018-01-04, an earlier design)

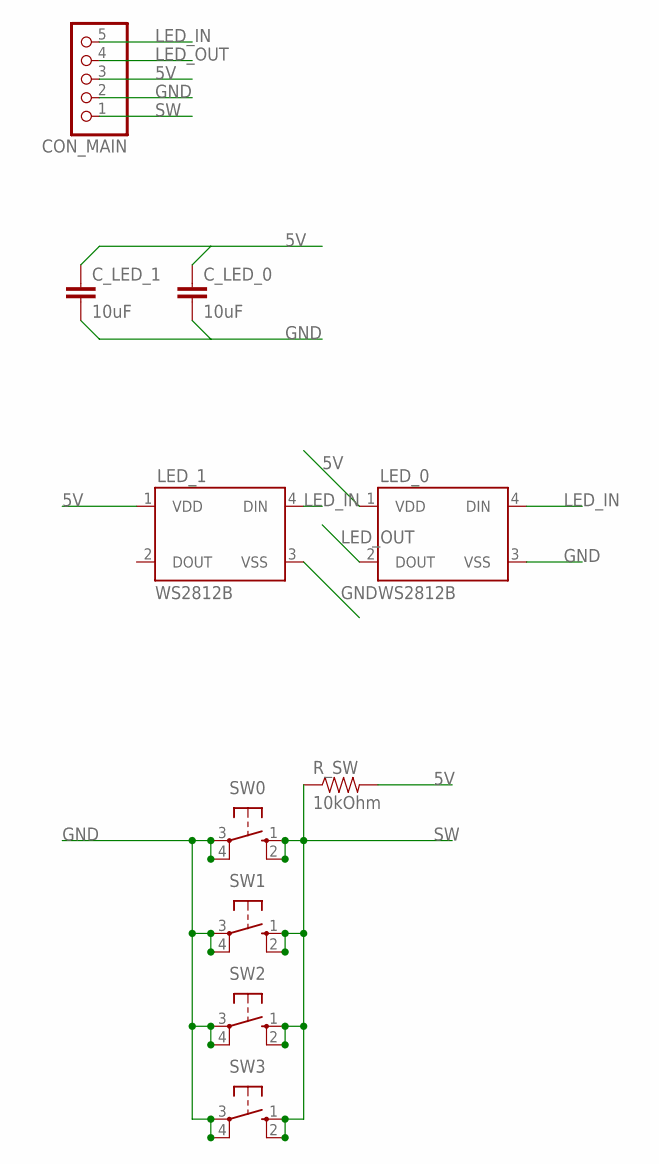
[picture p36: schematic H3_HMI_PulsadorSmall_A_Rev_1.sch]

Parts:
CON_MAIN: PINHD-1X5/90; 1X05/90
C_LED_0, C_LED_1: 10uF; C1206
LED_0, LED_1: WS2812B
R_SW: 10kOhm; 1206
SW0, SW1, SW2, SW3: 10-XX; B3F-10XX

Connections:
5V: CON_MAIN.3, C_LED_0.1, C_LED_1.1, LED_0.1 (VDD), LED_1.1 (VDD), R_SW.2
GND: CON_MAIN.2, C_LED_0.2, C_LED_1.2, LED_0.3 (VSS), LED_1.3 (VSS), SW0.3, SW0.4 (P1), SW1.3, SW1.4 (P1), SW2.3, SW2.4 (P1), SW3.3, SW3.4 (P1)
LED_IN: CON_MAIN.5, LED_0.4 (DIN), LED_1.4 (DIN)
LED_OUT: CON_MAIN.4, LED_0.2 (DOUT)
SW: CON_MAIN.1, R_SW.1, SW0.1 (S), SW0.2 (S1), SW1.1 (S), SW1.2 (S1), SW2.1 (S), SW2.2 (S1), SW3.1 (S), SW3.2 (S1)

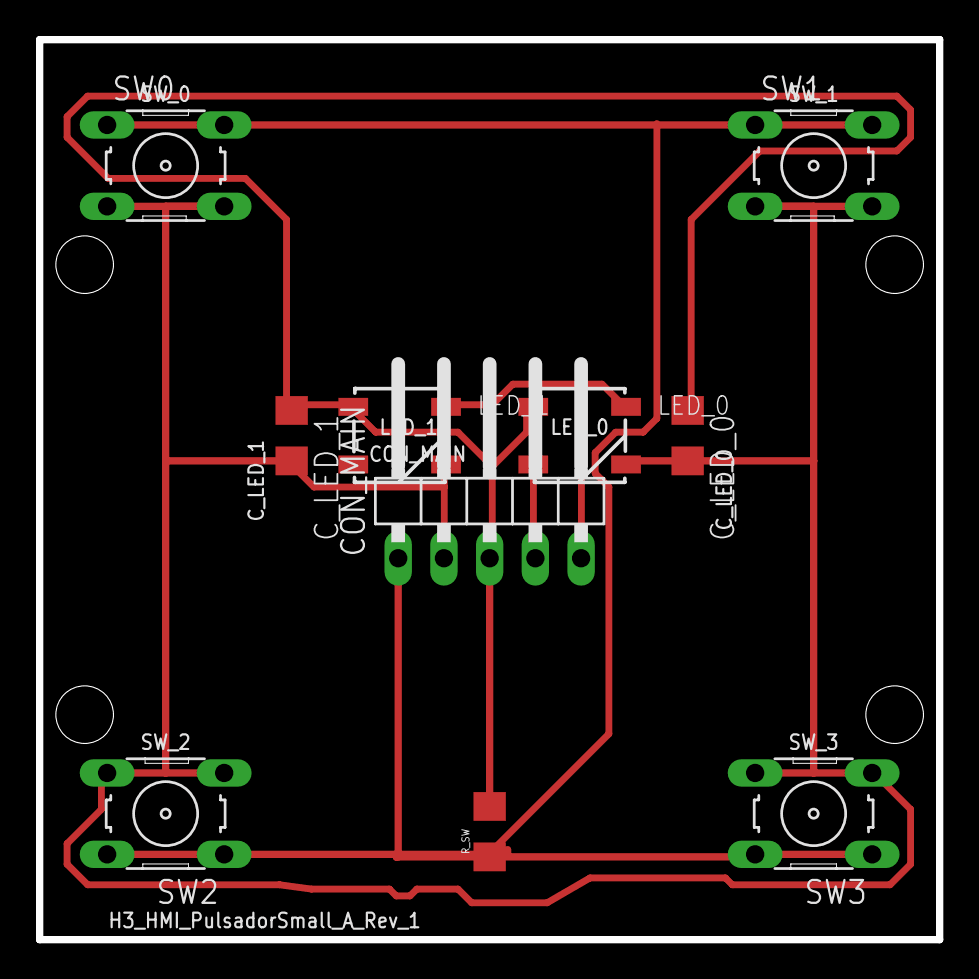
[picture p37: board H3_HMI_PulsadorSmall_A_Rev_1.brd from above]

Board: 2 copper layers, 50.0 x 50.0 mm, 10 parts (0 on the bottom side), 5 nets.

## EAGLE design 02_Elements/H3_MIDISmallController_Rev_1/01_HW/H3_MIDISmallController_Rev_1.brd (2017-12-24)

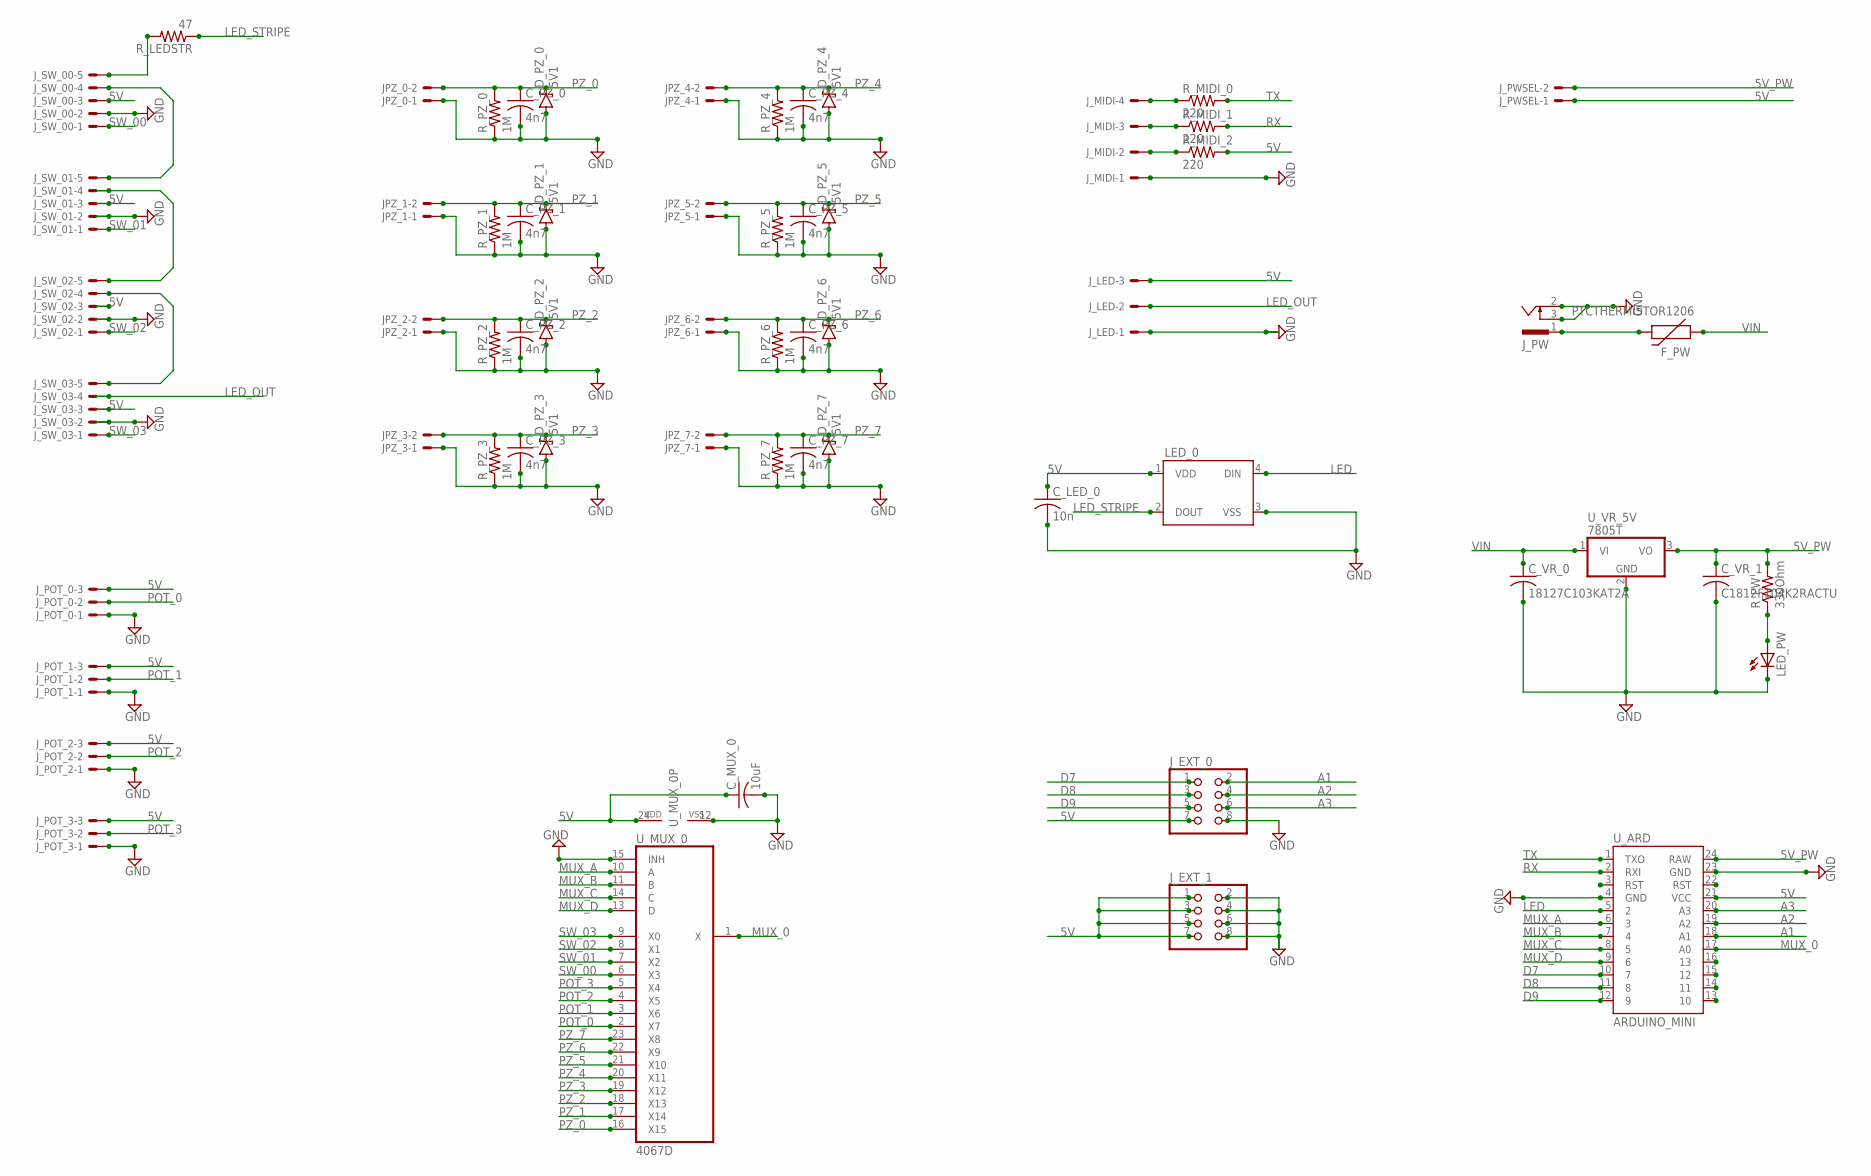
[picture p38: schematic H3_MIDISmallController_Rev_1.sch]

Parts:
C_LED_0: 10n; C1206
C_MUX_0: 10uF; C1206K
C_PZ_0, C_PZ_1, C_PZ_2, C_PZ_3, C_PZ_4, C_PZ_5, C_PZ_6, C_PZ_7: 4n7; C1206
C_VR_0: 18127C103KAT2A; C1206
C_VR_1: C1812F104K2RACTU; C1206
D_PZ_0, D_PZ_1, D_PZ_2, D_PZ_3, D_PZ_4, D_PZ_5, D_PZ_6, D_PZ_7: 5V1; DIODE-BZT52
F_PW: PTCTHERMISTOR1206; PTC-1206
JPZ_0, JPZ_1, JPZ_2, JPZ_3, JPZ_4, JPZ_5, JPZ_6, JPZ_7: 22-05-7028-02; 7395-02
J_EXT_0, J_EXT_1: PINHD-2X4/90; 2X04/90
J_LED: 22-05-7038-03; 7395-03
J_MIDI: 22-05-7048-04; 7395-04
J_POT_0, J_POT_1, J_POT_2, J_POT_3: 22-05-7038-03; 7395-03
J_PW: SCD-014A; SCD-014-A
J_PWSEL: 22-05-7028-02; 7395-02
J_SW_00, J_SW_01, J_SW_02, J_SW_03: 22-05-7058-05; 7395-05
LED_0: WS2812B
LED_PW: LEDSMT1206; 1206
R_LEDSTR: 47; M1206
R_MIDI_0, R_MIDI_1, R_MIDI_2: 220; M1206
R_PW: 330Ohm; M1206
R_PZ_0, R_PZ_1, R_PZ_2, R_PZ_3, R_PZ_4, R_PZ_5, R_PZ_6, R_PZ_7: 1M; M1206
U_ARD: ARDUINO_MINI
U_MUX_0: 4067D; SO24W
U_VR_5V: 7805T; TO220H

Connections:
5V: C_LED_0.1, C_MUX_0.1, J_EXT_0.7, J_EXT_1.1, J_EXT_1.3, J_EXT_1.5, J_EXT_1.7, J_LED.3, J_POT_0.3, J_POT_1.3, J_POT_2.3, J_POT_3.3, J_PWSEL.1, J_SW_00.3, J_SW_01.3, J_SW_02.3, J_SW_03.3, LED_0.1 (VDD), R_MIDI_2.2, U_ARD.21 (VCC), U_MUX_0.24 (VDD)
5V_PW: C_VR_1.1, J_PWSEL.2, R_PW.2, U_ARD.24 (RAW), U_VR_5V.3 (VO)
A1: J_EXT_0.2, U_ARD.18 (A1)
A2: J_EXT_0.4, U_ARD.19 (A2)
A3: J_EXT_0.6, U_ARD.20 (A3)
D7: J_EXT_0.1, U_ARD.10 (7)
D8: J_EXT_0.3, U_ARD.11 (8)
D9: J_EXT_0.5, U_ARD.12 (9)
GND: C_LED_0.2, C_MUX_0.2, C_PZ_0.2, C_PZ_1.2, C_PZ_2.2, C_PZ_3.2, C_PZ_4.2, C_PZ_5.2, C_PZ_6.2, C_PZ_7.2, C_VR_0.2, C_VR_1.2, D_PZ_0.A, D_PZ_1.A, D_PZ_2.A, D_PZ_3.A, D_PZ_4.A, D_PZ_5.A, D_PZ_6.A, D_PZ_7.A, JPZ_0.1, JPZ_1.1, JPZ_2.1, JPZ_3.1, JPZ_4.1, JPZ_5.1, JPZ_6.1, JPZ_7.1, J_EXT_0.8, J_EXT_1.2, J_EXT_1.4, J_EXT_1.6, J_EXT_1.8, J_LED.1, J_MIDI.1, J_POT_0.1, J_POT_1.1, J_POT_2.1, J_POT_3.1, J_PW.2, J_PW.3, J_SW_00.2, J_SW_01.2, J_SW_02.2, J_SW_03.2, LED_0.3 (VSS), LED_PW.C, R_PZ_0.1, R_PZ_1.1, R_PZ_2.1, R_PZ_3.1, R_PZ_4.1, R_PZ_5.1, R_PZ_6.1, R_PZ_7.1, U_ARD.4 (GND), U_ARD.23 (GND), U_MUX_0.12 (VSS), U_MUX_0.15 (INH), U_VR_5V.2 (GND)
LED: LED_0.4 (DIN), U_ARD.5 (2)
LED_IN2: J_SW_01.4, J_SW_02.5
LED_OUT: J_LED.2, J_SW_03.4
LED_STRIPE: LED_0.2 (DOUT), R_LEDSTR.1
MUX_0: U_ARD.17 (A0), U_MUX_0.1 (X)
MUX_A: U_ARD.6 (3), U_MUX_0.10 (A)
MUX_B: U_ARD.7 (4), U_MUX_0.11 (B)
MUX_C: U_ARD.8 (5), U_MUX_0.14 (C)
MUX_D: U_ARD.9 (6), U_MUX_0.13 (D)
unnamed: LED_PW.A, R_PW.1
unnamed: J_SW_00.4, J_SW_01.5
unnamed: J_SW_00.5, R_LEDSTR.2
unnamed: J_SW_02.4, J_SW_03.5
unnamed: F_PW.2, J_PW.1
unnamed: J_MIDI.2, R_MIDI_2.1
unnamed: J_MIDI.3, R_MIDI_1.1
unnamed: J_MIDI.4, R_MIDI_0.1
POT_0: J_POT_0.2, U_MUX_0.2 (X7)
POT_1: J_POT_1.2, U_MUX_0.3 (X6)
POT_2: J_POT_2.2, U_MUX_0.4 (X5)
POT_3: J_POT_3.2, U_MUX_0.5 (X4)
PZ_0: C_PZ_0.1, D_PZ_0.C, JPZ_0.2, R_PZ_0.2, U_MUX_0.16 (X15)
PZ_1: C_PZ_1.1, D_PZ_1.C, JPZ_1.2, R_PZ_1.2, U_MUX_0.17 (X14)
PZ_2: C_PZ_2.1, D_PZ_2.C, JPZ_2.2, R_PZ_2.2, U_MUX_0.18 (X13)
PZ_3: C_PZ_3.1, D_PZ_3.C, JPZ_3.2, R_PZ_3.2, U_MUX_0.19 (X12)
PZ_4: C_PZ_4.1, D_PZ_4.C, JPZ_4.2, R_PZ_4.2, U_MUX_0.20 (X11)
PZ_5: C_PZ_5.1, D_PZ_5.C, JPZ_5.2, R_PZ_5.2, U_MUX_0.21 (X10)
PZ_6: C_PZ_6.1, D_PZ_6.C, JPZ_6.2, R_PZ_6.2, U_MUX_0.22 (X9)
PZ_7: C_PZ_7.1, D_PZ_7.C, JPZ_7.2, R_PZ_7.2, U_MUX_0.23 (X8)
RX: R_MIDI_1.2, U_ARD.2 (RXI)
SW_00: J_SW_00.1, U_MUX_0.6 (X3)
SW_01: J_SW_01.1, U_MUX_0.7 (X2)
SW_02: J_SW_02.1, U_MUX_0.8 (X1)
SW_03: J_SW_03.1, U_MUX_0.9 (X0)
TX: R_MIDI_0.2, U_ARD.1 (TXO)
VIN: C_VR_0.1, F_PW.1, U_VR_5V.1 (VI)

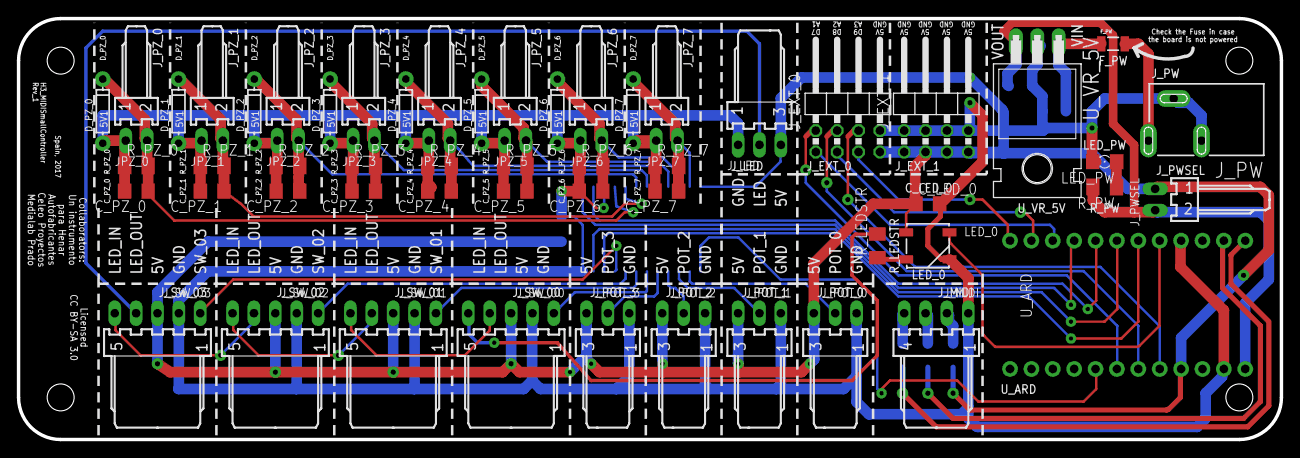
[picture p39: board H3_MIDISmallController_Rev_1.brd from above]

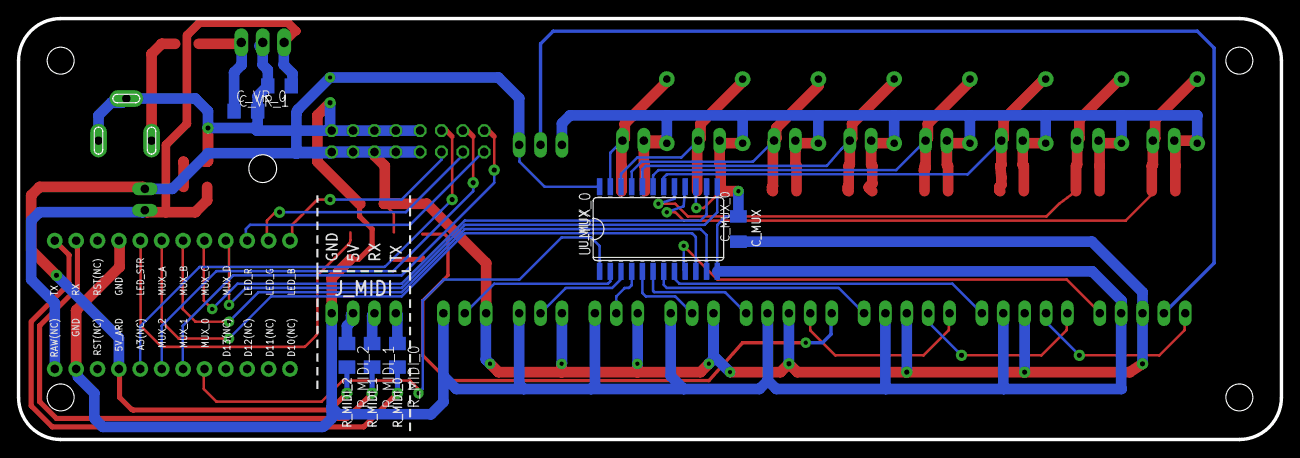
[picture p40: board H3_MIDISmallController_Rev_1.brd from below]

Board: 2 copper layers, 150.0 x 50.0 mm, 61 parts (7 on the bottom side), 45 nets.

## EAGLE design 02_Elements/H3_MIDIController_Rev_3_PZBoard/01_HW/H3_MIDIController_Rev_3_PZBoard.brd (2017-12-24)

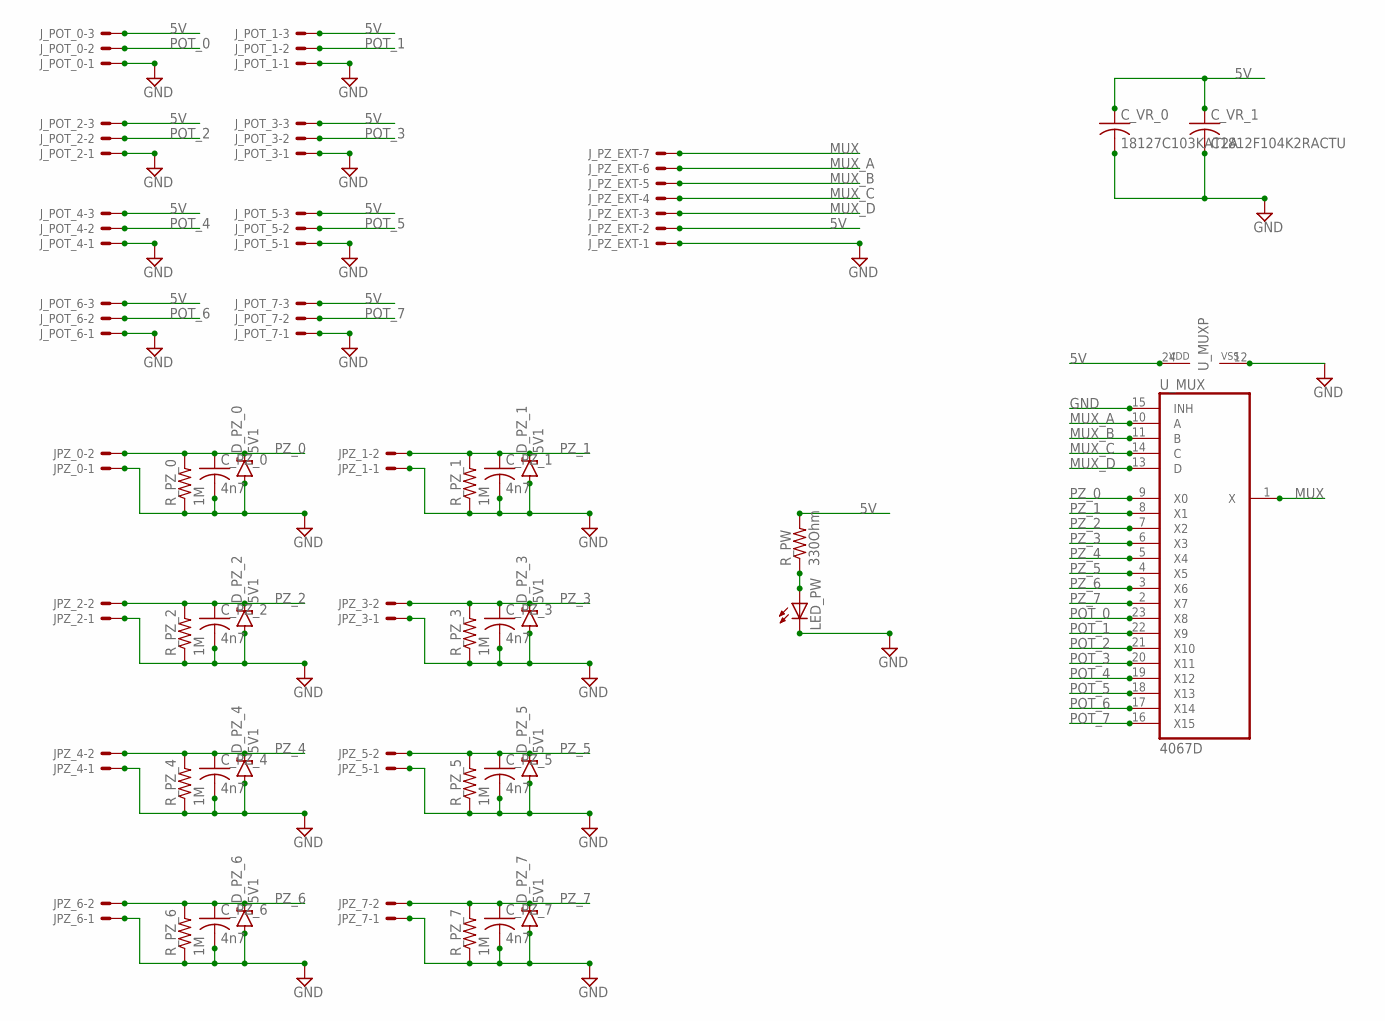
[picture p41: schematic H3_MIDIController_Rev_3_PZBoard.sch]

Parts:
C_PZ_0, C_PZ_1, C_PZ_2, C_PZ_3, C_PZ_4, C_PZ_5, C_PZ_6, C_PZ_7: 4n7; C1206
C_VR_0: 18127C103KAT2A; C1812K
C_VR_1: C1812F104K2RACTU; C1812K
D_PZ_0, D_PZ_1, D_PZ_2, D_PZ_3, D_PZ_4, D_PZ_5, D_PZ_6, D_PZ_7: 5V1; DIODE-BZT52
JPZ_0, JPZ_1, JPZ_2, JPZ_3, JPZ_4, JPZ_5, JPZ_6, JPZ_7: 22-05-7028-02; 7395-02
J_POT_0, J_POT_1, J_POT_2, J_POT_3, J_POT_4, J_POT_5, J_POT_6, J_POT_7: 22-05-7038-03; 7395-03
J_PZ_EXT: 22-05-7078-07; 7395-07
LED_PW: LEDSMT1206; 1206
R_PW: 330Ohm; M1206
R_PZ_0, R_PZ_1, R_PZ_2, R_PZ_3, R_PZ_4, R_PZ_5, R_PZ_6, R_PZ_7: 1M; M1206
U_MUX: 4067D; SO24W

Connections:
5V: C_VR_0.1, C_VR_1.1, J_POT_0.3, J_POT_1.3, J_POT_2.3, J_POT_3.3, J_POT_4.3, J_POT_5.3, J_POT_6.3, J_POT_7.3, J_PZ_EXT.2, R_PW.2, U_MUX.24 (VDD)
GND: C_PZ_0.2, C_PZ_1.2, C_PZ_2.2, C_PZ_3.2, C_PZ_4.2, C_PZ_5.2, C_PZ_6.2, C_PZ_7.2, C_VR_0.2, C_VR_1.2, D_PZ_0.A, D_PZ_1.A, D_PZ_2.A, D_PZ_3.A, D_PZ_4.A, D_PZ_5.A, D_PZ_6.A, D_PZ_7.A, JPZ_0.1, JPZ_1.1, JPZ_2.1, JPZ_3.1, JPZ_4.1, JPZ_5.1, JPZ_6.1, JPZ_7.1, J_POT_0.1, J_POT_1.1, J_POT_2.1, J_POT_3.1, J_POT_4.1, J_POT_5.1, J_POT_6.1, J_POT_7.1, J_PZ_EXT.1, LED_PW.C, R_PZ_0.1, R_PZ_1.1, R_PZ_2.1, R_PZ_3.1, R_PZ_4.1, R_PZ_5.1, R_PZ_6.1, R_PZ_7.1, U_MUX.12 (VSS), U_MUX.15 (INH)
MUX: J_PZ_EXT.7, U_MUX.1 (X)
MUX_A: J_PZ_EXT.6, U_MUX.10 (A)
MUX_B: J_PZ_EXT.5, U_MUX.11 (B)
MUX_C: J_PZ_EXT.4, U_MUX.14 (C)
MUX_D: J_PZ_EXT.3, U_MUX.13 (D)
unnamed: LED_PW.A, R_PW.1
POT_0: J_POT_0.2, U_MUX.23 (X8)
POT_1: J_POT_1.2, U_MUX.22 (X9)
POT_2: J_POT_2.2, U_MUX.21 (X10)
POT_3: J_POT_3.2, U_MUX.20 (X11)
POT_4: J_POT_4.2, U_MUX.19 (X12)
POT_5: J_POT_5.2, U_MUX.18 (X13)
POT_6: J_POT_6.2, U_MUX.17 (X14)
POT_7: J_POT_7.2, U_MUX.16 (X15)
PZ_0: C_PZ_0.1, D_PZ_0.C, JPZ_0.2, R_PZ_0.2, U_MUX.9 (X0)
PZ_1: C_PZ_1.1, D_PZ_1.C, JPZ_1.2, R_PZ_1.2, U_MUX.8 (X1)
PZ_2: C_PZ_2.1, D_PZ_2.C, JPZ_2.2, R_PZ_2.2, U_MUX.7 (X2)
PZ_3: C_PZ_3.1, D_PZ_3.C, JPZ_3.2, R_PZ_3.2, U_MUX.6 (X3)
PZ_4: C_PZ_4.1, D_PZ_4.C, JPZ_4.2, R_PZ_4.2, U_MUX.5 (X4)
PZ_5: C_PZ_5.1, D_PZ_5.C, JPZ_5.2, R_PZ_5.2, U_MUX.4 (X5)
PZ_6: C_PZ_6.1, D_PZ_6.C, JPZ_6.2, R_PZ_6.2, U_MUX.3 (X6)
PZ_7: C_PZ_7.1, D_PZ_7.C, JPZ_7.2, R_PZ_7.2, U_MUX.2 (X7)

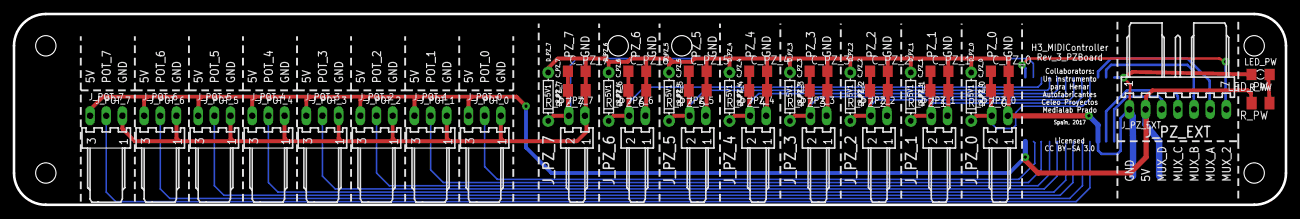
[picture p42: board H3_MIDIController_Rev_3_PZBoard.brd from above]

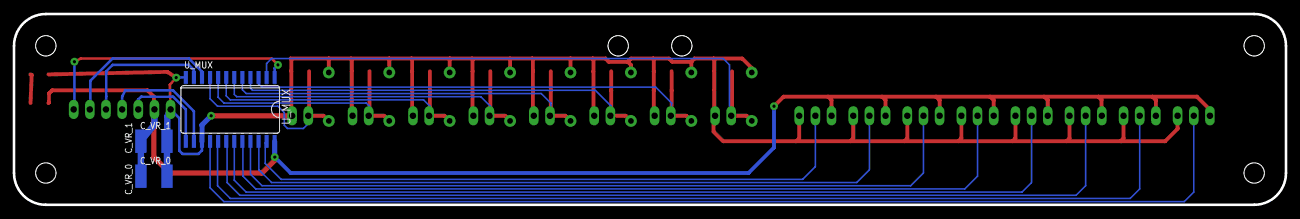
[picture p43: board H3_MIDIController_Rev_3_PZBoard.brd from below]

Board: 2 copper layers, 200.0 x 30.0 mm, 46 parts (3 on the bottom side), 24 nets.

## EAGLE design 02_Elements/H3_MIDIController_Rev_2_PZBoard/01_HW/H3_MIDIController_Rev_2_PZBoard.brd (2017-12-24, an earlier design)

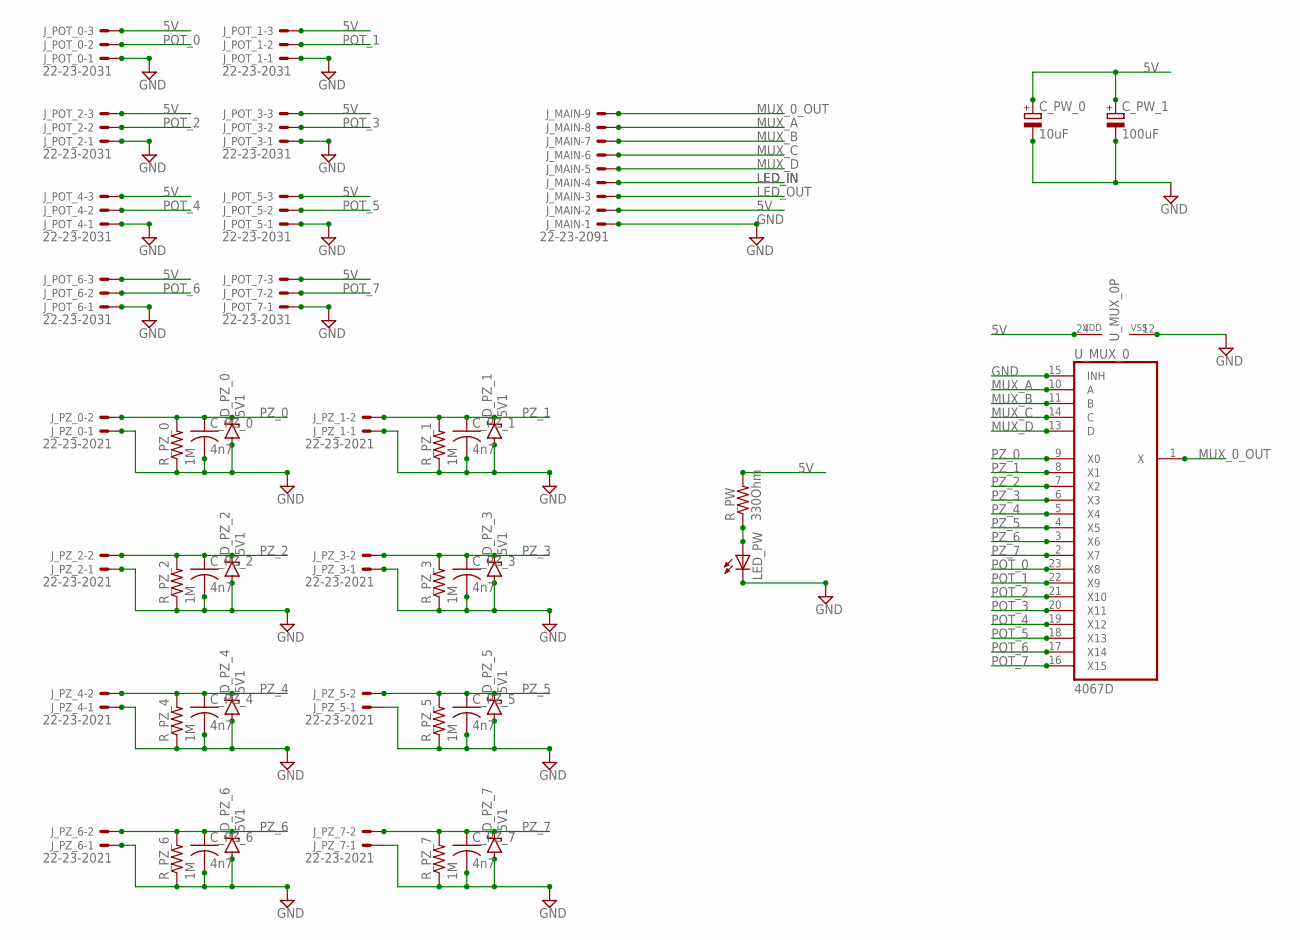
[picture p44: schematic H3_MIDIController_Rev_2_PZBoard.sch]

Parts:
C_PW_0: 10uF; TT2D6L
C_PW_1: 100uF; TT2D6L
C_PZ_0, C_PZ_1, C_PZ_2, C_PZ_3, C_PZ_4, C_PZ_5, C_PZ_6, C_PZ_7: 4n7; C1206
D_PZ_0, D_PZ_1, D_PZ_2, D_PZ_3, D_PZ_4, D_PZ_5, D_PZ_6, D_PZ_7: 5V1; DIODE-BZT52
J_MAIN: 22-23-2091
J_POT_0, J_POT_1, J_POT_2, J_POT_3, J_POT_4, J_POT_5, J_POT_6, J_POT_7: 22-23-2031
J_PZ_0, J_PZ_1, J_PZ_2, J_PZ_3, J_PZ_4, J_PZ_5, J_PZ_6, J_PZ_7: 22-23-2021
LED_PW: LEDSMT1206; 1206
R_PW: 330Ohm; M1206
R_PZ_0, R_PZ_1, R_PZ_2, R_PZ_3, R_PZ_4, R_PZ_5, R_PZ_6, R_PZ_7: 1M; M1206
U_MUX_0: 4067D; SO24W

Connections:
5V: C_PW_0.+, C_PW_1.+, J_MAIN.2, J_POT_0.3, J_POT_1.3, J_POT_2.3, J_POT_3.3, J_POT_4.3, J_POT_5.3, J_POT_6.3, J_POT_7.3, R_PW.2, U_MUX_0.24 (VDD)
GND: C_PW_0.-, C_PW_1.-, C_PZ_0.2, C_PZ_1.2, C_PZ_2.2, C_PZ_3.2, C_PZ_4.2, C_PZ_5.2, C_PZ_6.2, C_PZ_7.2, D_PZ_0.A, D_PZ_1.A, D_PZ_2.A, D_PZ_3.A, D_PZ_4.A, D_PZ_5.A, D_PZ_6.A, D_PZ_7.A, J_MAIN.1, J_POT_0.1, J_POT_1.1, J_POT_2.1, J_POT_3.1, J_POT_4.1, J_POT_5.1, J_POT_6.1, J_POT_7.1, J_PZ_0.1, J_PZ_1.1, J_PZ_2.1, J_PZ_3.1, J_PZ_4.1, J_PZ_5.1, J_PZ_6.1, J_PZ_7.1, LED_PW.C, R_PZ_0.1, R_PZ_1.1, R_PZ_2.1, R_PZ_3.1, R_PZ_4.1, R_PZ_5.1, R_PZ_6.1, R_PZ_7.1, U_MUX_0.12 (VSS), U_MUX_0.15 (INH)
LED_IN: J_MAIN.4
LED_OUT: J_MAIN.3
MUX_0_OUT: J_MAIN.9, U_MUX_0.1 (X)
MUX_A: J_MAIN.8, U_MUX_0.10 (A)
MUX_B: J_MAIN.7, U_MUX_0.11 (B)
MUX_C: J_MAIN.6, U_MUX_0.14 (C)
MUX_D: J_MAIN.5, U_MUX_0.13 (D)
unnamed: LED_PW.A, R_PW.1
POT_0: J_POT_0.2, U_MUX_0.23 (X8)
POT_1: J_POT_1.2, U_MUX_0.22 (X9)
POT_2: J_POT_2.2, U_MUX_0.21 (X10)
POT_3: J_POT_3.2, U_MUX_0.20 (X11)
POT_4: J_POT_4.2, U_MUX_0.19 (X12)
POT_5: J_POT_5.2, U_MUX_0.18 (X13)
POT_6: J_POT_6.2, U_MUX_0.17 (X14)
POT_7: J_POT_7.2, U_MUX_0.16 (X15)
PZ_0: C_PZ_0.1, D_PZ_0.C, J_PZ_0.2, R_PZ_0.2, U_MUX_0.9 (X0)
PZ_1: C_PZ_1.1, D_PZ_1.C, J_PZ_1.2, R_PZ_1.2, U_MUX_0.8 (X1)
PZ_2: C_PZ_2.1, D_PZ_2.C, J_PZ_2.2, R_PZ_2.2, U_MUX_0.7 (X2)
PZ_3: C_PZ_3.1, D_PZ_3.C, J_PZ_3.2, R_PZ_3.2, U_MUX_0.6 (X3)
PZ_4: C_PZ_4.1, D_PZ_4.C, J_PZ_4.2, R_PZ_4.2, U_MUX_0.5 (X4)
PZ_5: C_PZ_5.1, D_PZ_5.C, J_PZ_5.2, R_PZ_5.2, U_MUX_0.4 (X5)
PZ_6: C_PZ_6.1, D_PZ_6.C, J_PZ_6.2, R_PZ_6.2, U_MUX_0.3 (X6)
PZ_7: C_PZ_7.1, D_PZ_7.C, J_PZ_7.2, R_PZ_7.2, U_MUX_0.2 (X7)

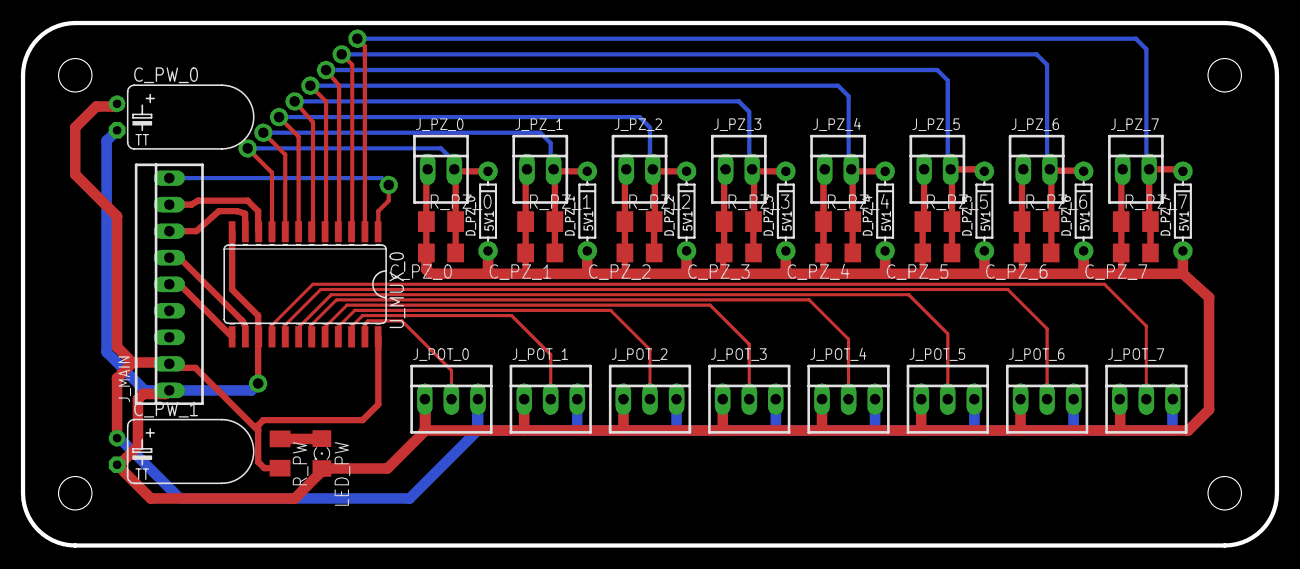
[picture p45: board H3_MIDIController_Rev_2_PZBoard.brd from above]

Board: 2 copper layers, 120.0 x 50.0 mm, 46 parts (0 on the bottom side), 24 nets.

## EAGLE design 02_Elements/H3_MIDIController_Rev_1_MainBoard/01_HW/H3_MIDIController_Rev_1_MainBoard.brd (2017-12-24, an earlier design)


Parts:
J_PZ_0, J_PZ_1, J_PZ_2, J_PZ_3, J_PZ_4, J_PZ_5, J_PZ_6, J_PZ_7: MA02; 02PA
J_SW_0, J_SW_1, J_SW_2, J_SW_3, J_SW_4, J_SW_5, J_SW_6, J_SW_7: MA05-1
LED1: RGBLED_CA-5MM; LED5MMRGB
POT_0, POT_1: EVUF2A; EVUF
R_MIDI_0, R_MIDI_1: 220Ohm; M1206
R_PZ_0, R_PZ_1, R_PZ_2, R_PZ_3, R_PZ_4, R_PZ_5, R_PZ_6, R_PZ_7: 1MOhm; M1206
R_RGB_B: 1MOhm; M1206
R_RGB_G: 1MOhm; M1206
R_RGB_R: 1MOhm; M1206
R_SWT_0, R_SWT_1: 1MOhm; M1206
SWT_0, SWT_1: 31-XX; B3F-31XX
U$1: MIDIJACK; CP-2350
U_ARD: ARDUINO_PRO_MICRO
U_MUX: 4067D; SO24W

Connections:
5V: J_SW_0.3, J_SW_1.3, J_SW_2.3, J_SW_3.3, J_SW_4.3, J_SW_5.3, J_SW_6.3, J_SW_7.3, LED1.2 (VCC), POT_0.3 (E), POT_1.3 (E), R_MIDI_1.2, R_SWT_0.2, R_SWT_1.2, U_ARD.21 (VCC), U_MUX.15 (INH), U_MUX.24 (VDD)
GND: J_PZ_0.1, J_PZ_1.1, J_PZ_2.1, J_PZ_3.1, J_PZ_4.1, J_PZ_5.1, J_PZ_6.1, J_PZ_7.1, J_SW_0.2, J_SW_1.2, J_SW_2.2, J_SW_3.2, J_SW_4.2, J_SW_5.2, J_SW_6.2, J_SW_7.2, POT_0.1 (A), POT_1.1 (A), R_PZ_0.1, R_PZ_1.1, R_PZ_2.1, R_PZ_3.1, R_PZ_4.1, R_PZ_5.1, R_PZ_6.1, R_PZ_7.1, SWT_0.1, SWT_1.1, U$1.2, U_ARD.3 (GND), U_ARD.4 (GND), U_ARD.23 (GND), U_MUX.12 (VSS)
LED_B: R_RGB_B.2, U_ARD.12 (*9)
LED_G: R_RGB_G.2, U_ARD.11 (8)
LED_IN: J_SW_0.5, U_ARD.5 (2)
LED_R: R_RGB_R.2, U_ARD.10 (7)
MIDI_TX: R_MIDI_0.1, U_ARD.1 (TXO)
MUX_A: U_ARD.6 (*3), U_MUX.10 (A)
MUX_B: U_ARD.7 (4), U_MUX.11 (B)
MUX_C: U_ARD.8 (*5), U_MUX.14 (C)
MUX_D: U_ARD.9 (*6), U_MUX.13 (D)
MUX_OUT: U_ARD.17 (A0), U_MUX.1 (X)
unnamed: J_SW_1.4, J_SW_2.5
unnamed: J_SW_0.4, J_SW_1.5
unnamed: LED1.1 (RED), R_RGB_R.1
unnamed: J_SW_2.4, J_SW_3.5
unnamed: R_MIDI_0.2, U$1.5
unnamed: J_SW_3.4, J_SW_4.5
unnamed: LED1.3 (GREEN), R_RGB_G.1
unnamed: J_SW_4.4, J_SW_5.5
unnamed: J_SW_5.4, J_SW_6.5
unnamed: R_MIDI_1.1, U$1.4
unnamed: J_SW_6.4, J_SW_7.5
unnamed: LED1.4 (BLUE), R_RGB_B.1
POT_0: POT_0.2 (S), U_ARD.18 (A1)
POT_1: POT_1.2 (S), U_ARD.19 (A2)
PZ_0: J_PZ_0.2, R_PZ_0.2, U_MUX.23 (X8)
PZ_1: J_PZ_1.2, R_PZ_1.2, U_MUX.22 (X9)
PZ_2: J_PZ_2.2, R_PZ_2.2, U_MUX.21 (X10)
PZ_3: J_PZ_3.2, R_PZ_3.2, U_MUX.20 (X11)
PZ_4: J_PZ_4.2, R_PZ_4.2, U_MUX.19 (X12)
PZ_5: J_PZ_5.2, R_PZ_5.2, U_MUX.18 (X13)
PZ_6: J_PZ_6.2, R_PZ_6.2, U_MUX.17 (X14)
PZ_7: J_PZ_7.2, R_PZ_7.2, U_MUX.16 (X15)
RAW: U_ARD.24 (RAW)
RST: U_ARD.22 (RESET)
SWT_0: R_SWT_0.1, SWT_0.2 (S), U_ARD.14 (11(MOSI))
SWT_1: R_SWT_1.1, SWT_1.2 (S), U_ARD.13 (*10)
SW_0: J_SW_0.1, U_MUX.9 (X0)
SW_1: J_SW_1.1, U_MUX.8 (X1)
SW_2: J_SW_2.1, U_MUX.7 (X2)
SW_3: J_SW_3.1, U_MUX.6 (X3)
SW_4: J_SW_4.1, U_MUX.5 (X4)
SW_5: J_SW_5.1, U_MUX.4 (X5)
SW_6: J_SW_6.1, U_MUX.3 (X6)
SW_7: J_SW_7.1, U_MUX.2 (X7)



Board: 2 copper layers, 100.0 x 50.0 mm, 39 parts (16 on the bottom side), 44 nets.

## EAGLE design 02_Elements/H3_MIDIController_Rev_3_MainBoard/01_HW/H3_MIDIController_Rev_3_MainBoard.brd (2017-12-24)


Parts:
C_MUX_0, C_MUX_1: 10uF; C1206K
C_VR_0: 18127C103KAT2A; C1812K
C_VR_1: C1812F104K2RACTU; C1812K
F_PW: PTCTHERMISTOR1206; PTC-1206
J_MIDI: 22-05-7048-04; 7395-04
J_PW: SCD-014A; SCD-014-A
J_PZ_EXT: 22-05-7078-07; 7395-07
J_SW_00, J_SW_01, J_SW_02, J_SW_03, J_SW_04, J_SW_05, J_SW_06, J_SW_07, J_SW_08, J_SW_09, J_SW_10, J_SW_11, J_SW_12, J_SW_13, J_SW_14, J_SW_15, J_SW_16, J_SW_17, J_SW_18, J_SW_19, J_SW_20, J_SW_21, J_SW_22, J_SW_23, J_SW_24, J_SW_25, J_SW_26, J_SW_27, J_SW_28, J_SW_29, J_SW_30, J_SW_31: 22-05-7058-05; 7395-05
LED_PW: LEDSMT1206; 1206
LED_RGB: RGBLED5050
R_LEDSTR: 47; M1206
R_LED_B: 330; M1206
R_LED_G: 330; M1206
R_LED_R: 330; M1206
R_MIDI_0, R_MIDI_1, R_MIDI_2: 220; M1206
R_PW: 330Ohm; M1206
U_ARD: ARDUINO_MINI
U_MUX_0, U_MUX_1: 4067D; SO24W
U_VR_5V: 7805T; TO220H

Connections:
5V: C_MUX_0.1, C_MUX_1.1, J_SW_00.3, J_SW_01.3, J_SW_02.3, J_SW_03.3, J_SW_04.3, J_SW_05.3, J_SW_06.3, J_SW_07.3, J_SW_08.3, J_SW_09.3, J_SW_10.3, J_SW_11.3, J_SW_12.3, J_SW_13.3, J_SW_14.3, J_SW_15.3, J_SW_16.3, J_SW_17.3, J_SW_18.3, J_SW_19.3, J_SW_20.3, J_SW_21.3, J_SW_22.3, J_SW_23.3, J_SW_24.3, J_SW_25.3, J_SW_26.3, J_SW_27.3, J_SW_28.3, J_SW_29.3, J_SW_30.3, J_SW_31.3, U_MUX_0.24 (VDD), U_MUX_1.24 (VDD)
5V_ARD: J_PZ_EXT.2, LED_RGB.1 (GREEN_A), LED_RGB.2 (RED_A), LED_RGB.3 (BLUE_A), R_MIDI_2.2, U_ARD.21 (VCC)
5V_PW: C_VR_1.1, R_PW.2, U_VR_5V.3 (VO)
GND: C_MUX_0.2, C_MUX_1.2, C_VR_0.2, C_VR_1.2, J_MIDI.1, J_PW.2, J_PW.3, J_PZ_EXT.1, J_SW_00.2, J_SW_01.2, J_SW_02.2, J_SW_03.2, J_SW_04.2, J_SW_05.2, J_SW_06.2, J_SW_07.2, J_SW_08.2, J_SW_09.2, J_SW_10.2, J_SW_11.2, J_SW_12.2, J_SW_13.2, J_SW_14.2, J_SW_15.2, J_SW_16.2, J_SW_17.2, J_SW_18.2, J_SW_19.2, J_SW_20.2, J_SW_21.2, J_SW_22.2, J_SW_23.2, J_SW_24.2, J_SW_25.2, J_SW_26.2, J_SW_27.2, J_SW_28.2, J_SW_29.2, J_SW_30.2, J_SW_31.2, LED_PW.C, U_ARD.4 (GND), U_ARD.23 (GND), U_MUX_0.12 (VSS), U_MUX_0.15 (INH), U_MUX_1.12 (VSS), U_MUX_1.15 (INH), U_VR_5V.2 (GND)
LED_B: R_LED_B.2, U_ARD.12 (9)
LED_G: R_LED_G.2, U_ARD.11 (8)
LED_IN1: J_SW_00.4, J_SW_01.5
LED_IN2: J_SW_01.4, J_SW_02.5
LED_IN3: J_SW_02.4, J_SW_03.5
LED_IN4: J_SW_03.4, J_SW_04.5
LED_IN5: J_SW_04.4, J_SW_05.5
LED_IN6: J_SW_05.4, J_SW_06.5
LED_IN7: J_SW_07.4, J_SW_08.5
LED_IN8: J_SW_08.4, J_SW_09.5
LED_IN9: J_SW_09.4, J_SW_10.5
LED_IN10: J_SW_10.4, J_SW_11.5
LED_IN11: J_SW_11.4, J_SW_12.5
LED_IN12: J_SW_12.4, J_SW_13.5
LED_IN13: J_SW_13.4, J_SW_14.5
LED_IN14: J_SW_14.4, J_SW_15.5
LED_IN15: J_SW_16.4, J_SW_17.5
LED_IN16: J_SW_17.4, J_SW_18.5
LED_IN17: J_SW_18.4, J_SW_19.5
LED_IN18: J_SW_19.4, J_SW_20.5
LED_IN19: J_SW_20.4, J_SW_21.5
LED_IN20: J_SW_21.4, J_SW_22.5
LED_IN21: J_SW_23.4, J_SW_24.5
LED_IN22: J_SW_24.4, J_SW_25.5
LED_IN23: J_SW_25.4, J_SW_26.5
LED_IN24: J_SW_26.4, J_SW_27.5
LED_IN25: J_SW_27.4, J_SW_28.5
LED_IN26: J_SW_28.4, J_SW_29.5
LED_IN27: J_SW_29.4, J_SW_30.5
LED_IN28: J_SW_30.4, J_SW_31.5
LED_OUT: J_SW_31.4
LED_R: R_LED_R.2, U_ARD.10 (7)
LED_STRIPE: R_LEDSTR.1, U_ARD.5 (2)
LED_SW_00_15: J_SW_15.4, J_SW_16.5
MUX_0: U_ARD.17 (A0), U_MUX_0.1 (X)
MUX_1: U_ARD.18 (A1), U_MUX_1.1 (X)
MUX_2: J_PZ_EXT.7, U_ARD.19 (A2)
MUX_A: J_PZ_EXT.6, U_ARD.6 (3), U_MUX_0.10 (A), U_MUX_1.10 (A)
MUX_B: J_PZ_EXT.5, U_ARD.7 (4), U_MUX_0.11 (B), U_MUX_1.11 (B)
MUX_C: J_PZ_EXT.4, U_ARD.8 (5), U_MUX_0.14 (C), U_MUX_1.14 (C)
MUX_D: J_PZ_EXT.3, U_ARD.9 (6), U_MUX_0.13 (D), U_MUX_1.13 (D)
unnamed: F_PW.2, J_PW.1
unnamed: J_SW_00.5, R_LEDSTR.2
unnamed: LED_PW.A, R_PW.1
unnamed: J_SW_22.4, J_SW_23.5
unnamed: LED_RGB.4 (BLUE_C), R_LED_B.1
unnamed: LED_RGB.6 (GREEN_C), R_LED_G.1
unnamed: LED_RGB.5 (RED_C), R_LED_R.1
unnamed: J_MIDI.2, R_MIDI_2.1
unnamed: J_MIDI.3, R_MIDI_1.1
unnamed: J_MIDI.4, R_MIDI_0.1
unnamed: J_SW_06.4, J_SW_07.5
RST: U_ARD.3 (RST), U_ARD.22 (RST)
RX: R_MIDI_1.2, U_ARD.2 (RXI)
SW_0: U_ARD.13 (10)
SW_00: J_SW_00.1, U_MUX_0.9 (X0)
SW_1: U_ARD.14 (11)
SW_01: J_SW_01.1, U_MUX_0.8 (X1)
SW_2: U_ARD.15 (12)
SW_02: J_SW_02.1, U_MUX_0.7 (X2)
SW_3: U_ARD.16 (13)
SW_03: J_SW_03.1, U_MUX_0.6 (X3)
SW_04: J_SW_04.1, U_MUX_0.5 (X4)
SW_05: J_SW_05.1, U_MUX_0.4 (X5)
SW_06: J_SW_06.1, U_MUX_0.3 (X6)
SW_07: J_SW_07.1, U_MUX_0.2 (X7)
SW_08: J_SW_08.1, U_MUX_0.23 (X8)
SW_09: J_SW_09.1, U_MUX_0.22 (X9)
SW_10: J_SW_10.1, U_MUX_0.21 (X10)
SW_11: J_SW_11.1, U_MUX_0.20 (X11)
SW_12: J_SW_12.1, U_MUX_0.19 (X12)
SW_13: J_SW_13.1, U_MUX_0.18 (X13)
SW_14: J_SW_14.1, U_MUX_0.17 (X14)
SW_15: J_SW_15.1, U_MUX_0.16 (X15)
SW_16: J_SW_16.1, U_MUX_1.9 (X0)
SW_17: J_SW_17.1, U_MUX_1.8 (X1)
SW_18: J_SW_18.1, U_MUX_1.7 (X2)
SW_19: J_SW_19.1, U_MUX_1.6 (X3)
SW_20: J_SW_20.1, U_MUX_1.5 (X4)
SW_21: J_SW_21.1, U_MUX_1.4 (X5)
SW_22: J_SW_22.1, U_MUX_1.3 (X6)
SW_23: J_SW_23.1, U_MUX_1.2 (X7)
SW_24: J_SW_24.1, U_MUX_1.23 (X8)
SW_25: J_SW_25.1, U_MUX_1.22 (X9)
SW_26: J_SW_26.1, U_MUX_1.21 (X10)
SW_27: J_SW_27.1, U_MUX_1.20 (X11)
SW_28: J_SW_28.1, U_MUX_1.19 (X12)
SW_29: J_SW_29.1, U_MUX_1.18 (X13)
SW_30: J_SW_30.1, U_MUX_1.17 (X14)
SW_31: J_SW_31.1, U_MUX_1.16 (X15)
TX: R_MIDI_0.2, U_ARD.1 (TXO)
VIN: C_VR_0.1, F_PW.1, U_VR_5V.1 (VI)



Board: 2 copper layers, 300.0 x 50.0 mm, 54 parts (24 on the bottom side), 91 nets.

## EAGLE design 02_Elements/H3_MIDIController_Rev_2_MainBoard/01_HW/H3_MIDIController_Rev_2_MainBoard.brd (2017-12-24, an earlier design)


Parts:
C_PW_0: 10uF; TT2D6L
C_PW_1: 100uF; TT2D6L
D_RGBLED: RGBLED_CA-5MM; LED5MMRGB
J_MAIN_0, J_MAIN_1, J_MAIN_2: 22-23-2091
J_PW: SCD-014A; SCD-014-A
LED_PW: LEDSMT1206; 1206
R_LEDSTR: 47; M1206
R_LED_B: 330; M1206
R_LED_G: 330; M1206
R_LED_R: 330; M1206
R_PW: 330Ohm; M1206
U_ARD: ARDUINO_MINI
U_VR: 7805DT; TO252

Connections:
5V_ARD: D_RGBLED.2 (VCC), U_ARD.21 (VCC)
5V_PW: C_PW_1.+, J_MAIN_0.2, J_MAIN_1.2, J_MAIN_2.2, R_PW.2, U_VR.2 (VO)
GND: C_PW_0.-, C_PW_1.-, J_MAIN_0.1, J_MAIN_1.1, J_MAIN_2.1, J_PW.2, J_PW.3, LED_PW.C, U_ARD.4 (GND), U_ARD.23 (GND), U_VR.3 (GND)
LED_B: R_LED_B.2, U_ARD.12 (9)
LED_G: R_LED_G.2, U_ARD.11 (8)
LED_OUT: J_MAIN_0.3, J_MAIN_1.4
LED_OUT1: J_MAIN_1.3, J_MAIN_2.4
LED_R: R_LED_R.2, U_ARD.10 (7)
LED_STRIPE: R_LEDSTR.2, U_ARD.5 (2)
MUX_0_OUT: J_MAIN_0.9, U_ARD.17 (A0)
MUX_1_OUT: J_MAIN_1.9, U_ARD.18 (A1)
MUX_2_OUT: J_MAIN_2.9, U_ARD.19 (A2)
MUX_A: J_MAIN_0.8, J_MAIN_1.8, J_MAIN_2.8, U_ARD.6 (3)
MUX_B: J_MAIN_0.7, J_MAIN_1.7, J_MAIN_2.7, U_ARD.7 (4)
MUX_C: J_MAIN_0.6, J_MAIN_1.6, J_MAIN_2.6, U_ARD.8 (5)
MUX_D: J_MAIN_0.5, J_MAIN_1.5, J_MAIN_2.5, U_ARD.9 (6)
unnamed: J_MAIN_0.4, R_LEDSTR.1
unnamed: LED_PW.A, R_PW.1
unnamed: D_RGBLED.4 (BLUE), R_LED_B.1
unnamed: D_RGBLED.3 (GREEN), R_LED_G.1
unnamed: D_RGBLED.1 (RED), R_LED_R.1
RST: U_ARD.3 (RST), U_ARD.22 (RST)
RX: U_ARD.2 (RXI)
SW_0: U_ARD.13 (10)
SW_1: U_ARD.14 (11)
SW_2: U_ARD.15 (12)
SW_3: U_ARD.16 (13)
TX: U_ARD.1 (TXO)
VIN: C_PW_0.+, J_PW.1, U_VR.1 (VI)



Board: 2 copper layers, 120.0 x 50.0 mm, 15 parts (5 on the bottom side), 23 nets.

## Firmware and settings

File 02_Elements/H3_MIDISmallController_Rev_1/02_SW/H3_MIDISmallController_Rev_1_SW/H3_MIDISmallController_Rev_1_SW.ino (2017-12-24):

// Name: H3_MIDISmallController_Rev_1_SW
// Programmer: Pablo dMM (Pablodmm.isp@gmail.com)
// Date: Novemeber 2017
// Description: Test Code for H3_MIDISmallController_Rev_31 Board. Part of the Henar#3 project in which Autofabricantes collaborates.

// Library Import
#include <Adafruit_NeoPixel.h>
#include <MIDIUSB.h>

// MIDI MSSG VALUES

// First Byte
const byte NOTE_ON        = 144;
const byte NOTE_OFF       = 128;
const byte CONTROL        = 176;

// SECOND BYTE GENERAL 
const byte CTRL_VOL       =   7;
const byte CTRL_MOD       =   1;
const byte CTRL_EFCT1     =  12;
const byte CTRL_EFCT2     =  13;
const byte CTRL_NOTEOFF   = 123;

// SECOND BYTE NOTE VALUES ------------------------------------------------------------------------------------------------------------------------------------
// OCTAVE 00              || OCTAVE 01               || OCTAVE 02               || OCTAVE 03              || OCTAVE 04               || OCTAVE 05
//-------------------------------------------------------------------------------------------------------------------------------------------------------------
const byte NOTE_C0  =  0  ;const byte NOTE_C1  = 12  ;const byte NOTE_C2  = 24  ;const byte NOTE_C3  = 36  ;const byte NOTE_C4  = 48  ;const byte NOTE_C5  = 60;
const byte NOTE_C0s =  1  ;const byte NOTE_C1s = 13  ;const byte NOTE_C2s = 25  ;const byte NOTE_C3s = 37  ;const byte NOTE_C4s = 49  ;const byte NOTE_C5s = 61;
const byte NOTE_D0  =  2  ;const byte NOTE_D1  = 14  ;const byte NOTE_D2  = 26  ;const byte NOTE_D3  = 38  ;const byte NOTE_D4  = 50  ;const byte NOTE_D5  = 62;
const byte NOTE_D0s =  3  ;const byte NOTE_D1s = 15  ;const byte NOTE_D2s = 27  ;const byte NOTE_D3s = 39  ;const byte NOTE_D4s = 51  ;const byte NOTE_D5s = 63;
const byte NOTE_E0  =  4  ;const byte NOTE_E1  = 16  ;const byte NOTE_E2  = 28  ;const byte NOTE_E3  = 40  ;const byte NOTE_E4  = 52  ;const byte NOTE_E5  = 64;
const byte NOTE_F0  =  5  ;const byte NOTE_F1  = 17  ;const byte NOTE_F2  = 29  ;const byte NOTE_F3  = 41  ;const byte NOTE_F4  = 53  ;const byte NOTE_F5  = 65;
const byte NOTE_F0s =  6  ;const byte NOTE_F1s = 18  ;const byte NOTE_F2s = 30  ;const byte NOTE_F3s = 42  ;const byte NOTE_F4s = 54  ;const byte NOTE_F5s = 66;
const byte NOTE_G0  =  7  ;const byte NOTE_G1  = 19  ;const byte NOTE_G2  = 31  ;const byte NOTE_G3  = 43  ;const byte NOTE_G4  = 55  ;const byte NOTE_G5  = 67;
const byte NOTE_G0s =  8  ;const byte NOTE_G1s = 20  ;const byte NOTE_G2s = 32  ;const byte NOTE_G3s = 44  ;const byte NOTE_G4s = 56  ;const byte NOTE_G5s = 68;
const byte NOTE_A0  =  9  ;const byte NOTE_A1  = 21  ;const byte NOTE_A2  = 33  ;const byte NOTE_A3  = 45  ;const byte NOTE_A4  = 57  ;const byte NOTE_A5  = 69;
const byte NOTE_A0s = 10  ;const byte NOTE_A1s = 22  ;const byte NOTE_A2s = 34  ;const byte NOTE_A3s = 46  ;const byte NOTE_A4s = 58  ;const byte NOTE_A5s = 70;
const byte NOTE_B0  = 11  ;const byte NOTE_B1  = 23  ;const byte NOTE_B2  = 35  ;const byte NOTE_B3  = 47  ;const byte NOTE_B4  = 59  ;const byte NOTE_B5  = 71;

// SECOND BYTE NOTE VALUES -----------------------------------------------------------------------------------------------------------
// OCTAVE 06              || OCTAVE 07               || OCTAVE 08               || OCTAVE 09               || OCTAVE 10           
//------------------------------------------------------------------------------------------------------------------------------------
const byte NOTE_C6  = 72  ;const byte NOTE_C7  = 84  ;const byte NOTE_C8  = 96  ;const byte NOTE_C9  =108  ;const byte NOTE_C10  =120;
const byte NOTE_C6s = 73  ;const byte NOTE_C7s = 85  ;const byte NOTE_C8s = 97  ;const byte NOTE_C9s =109  ;const byte NOTE_C10s =121;
const byte NOTE_D6  = 74  ;const byte NOTE_D7  = 86  ;const byte NOTE_D8  = 98  ;const byte NOTE_D9  =110  ;const byte NOTE_D10  =122;
const byte NOTE_D6s = 75  ;const byte NOTE_D7s = 87  ;const byte NOTE_D8s = 99  ;const byte NOTE_D9s =111  ;const byte NOTE_D10s =123;
const byte NOTE_E6  = 76  ;const byte NOTE_E7  = 88  ;const byte NOTE_E8  =100  ;const byte NOTE_E9  =112  ;const byte NOTE_E10  =124;
const byte NOTE_F6  = 77  ;const byte NOTE_F7  = 89  ;const byte NOTE_F8  =101  ;const byte NOTE_F9  =113  ;const byte NOTE_F10  =125;
const byte NOTE_F6s = 78  ;const byte NOTE_F7s = 90  ;const byte NOTE_F8s =102  ;const byte NOTE_F9s =114  ;const byte NOTE_F10s =126;
const byte NOTE_G6  = 79  ;const byte NOTE_G7  = 91  ;const byte NOTE_G8  =103  ;const byte NOTE_G9  =115;
const byte NOTE_G6s = 80  ;const byte NOTE_G7s = 92  ;const byte NOTE_G8s =104  ;const byte NOTE_G9s =116;
const byte NOTE_A6  = 81  ;const byte NOTE_A7  = 93  ;const byte NOTE_A8  =105  ;const byte NOTE_A9  =117;
const byte NOTE_A6s = 82  ;const byte NOTE_A7s = 94  ;const byte NOTE_A8s =106  ;const byte NOTE_A9s =118;
const byte NOTE_B6  = 83  ;const byte NOTE_B7  = 95  ;const byte NOTE_B8  =107  ;const byte NOTE_B9  =119;
                                                            
// -----------------------------------------------------------------------------------------------------------------------------------------
// -----------------------------------------------------Control Arrays for SW PAD-----------------------------------------------------------
// -----------------------------------------------------------------------------------------------------------------------------------------
// SW Control General Parameters
// -----------------------------------------------------------------------------------------------------------------------------------------
const int  SW_Q         =   4;      // SW_Q Number of present SW Pad (Big or Small)
int  SW_CTRL[SW_Q];                 // SW_Pad Global Control Array (Initialized to OFF in Setup)
const int SW_THR        = 512;      // Switch Threshold (Fake Digital)
int   MENU_MODE         =   0;      // Menu Mode Flag (Values 0, 1)
const int FADESTEPS_Q   =   2;      // GENERAL FadeSteps
const int FADEDELAY_Q   =   5;      // GENERAL FadeDelay

// Control Arrays for SW_Pad
//------------------------------------------------------------------------------------------------------------------------------------------
// SW_Q                || SW_ACT                  || SW_VAR         || SW_INIT                                         || Comments
//------------------------------------------------------------------------------------------------------------------------------------------
const int SW_00_Q = 1  ;const int SW_00_ACT = 0   ;int SW_00  = 0   ;int SW_00_INIT  = 0;                      
const int SW_01_Q = 1  ;const int SW_01_ACT = 1   ;int SW_01  = 0   ;int SW_01_INIT  = SW_00_Q;               
const int SW_02_Q = 1  ;const int SW_02_ACT = 2   ;int SW_02  = 0   ;int SW_02_INIT  = (SW_00_Q + SW_01_Q);
const int SW_03_Q = 1  ;const int SW_03_ACT = 3   ;int SW_03  = 0   ;int SW_03_INIT  = (SW_00_Q + SW_01_Q + SW_02_Q);


//------------------------------------------------------------------------------------------------------------------------------------------
// COLOR RED [0:255]          || COLOR GREEN [0:255]         || COLOR BLUE [0:255]           || Comments
//------------------------------------------------------------------------------------------------------------------------------------------
const byte GEN_R_OFF   =  40  ;const byte GEN_G_OFF   =  40  ;const byte GEN_B_OFF  =   40;   // SW_GENERAL OFF LED COLOR
const byte GEN_R_ON    =  40  ;const byte GEN_G_ON    =  40  ;const byte GEN_B_ON   =  255;   // SW_GENERAL OFF LED COLOR
const byte SW_00_R_ON  =   0  ;const byte SW_00_G_ON  = 100  ;const byte SW_00_B_ON  = 100;  // SW_GENERAL OFF LED COLOR
const byte SW_01_R_ON  = 100  ;const byte SW_01_G_ON  = 100  ;const byte SW_01_B_ON  =   0;  // SW_SCALE ON LED COLOR
const byte SW_02_R_ON  = 100  ;const byte SW_02_G_ON  =   0  ;const byte SW_02_B_ON  = 100;  // SW_MODE ON LED COLOR
const byte SW_03_R_ON  =   0  ;const byte SW_03_G_ON  = 100  ;const byte SW_03_B_ON  = 255;  // SW_MODE ON LED COLOR

// -----------------------------------------------------------------------------------------------------------------------------------------
// -----------------------------------------------------Control Arrays for PZ PAD-----------------------------------------------------------
// -----------------------------------------------------------------------------------------------------------------------------------------
// PZ Control General Parameters
// -----------------------------------------------------------------------------------------------------------------------------------------
const int PZ_Q          =   7;   // Piezo Quantity
const int PZ_RLX        =   5;   // Piezo Relax Time (ms)
const int PZ_THR_G      = 400;   // Piezo Sensor Threshold for PZ 7 (General)

// PZ Control Matrix            |PZ_PAD_0  |PZ_PAD_1  |PZ_PAD_2  |PZ_PAD_3  |PZ_PAD_4  |PZ_PAD_5  |PZ_PAD_6    || Comments
//------------------------------------------------------------------------------------------------------------------------------------------
byte PZ_MIDI_BYTE_1[2][PZ_Q] = {{NOTE_ON,  NOTE_ON,   NOTE_ON,   NOTE_ON,   NOTE_ON,   NOTE_ON,   NOTE_ON  },   // MIDI First BYTE NOTE_ON
                                {NOTE_OFF, NOTE_OFF,  NOTE_OFF,  NOTE_OFF,  NOTE_OFF,  NOTE_OFF,  NOTE_OFF }
};  // MIDI First BYTE NOTE_OFF
//------------------------------------------------------------------------------------------------------------------------------------------
byte PZ_MIDI_BYTE_2[6][PZ_Q] = {{NOTE_C1,  NOTE_D1,   NOTE_E1,   NOTE_F1,   NOTE_G1,   NOTE_A1,   NOTE_B1  },   // Escala Mayor             I-II-III-IV-V-VI-VII
                                {NOTE_C1,  NOTE_D1,   NOTE_D1s,  NOTE_F1,   NOTE_G1,   NOTE_A1,   NOTE_A1s },   // Escala Menor Natural     I-II-IIIb-IV-V-VI-VIIb
                                {NOTE_C1,  NOTE_E1,   NOTE_G1,   NOTE_B1,   NOTE_C2,   NOTE_E2,   NOTE_G2  },   // Escala Arpegio Maj7      I-III-V-VII-I'-III'-V'
                                {NOTE_C1,  NOTE_D1s,  NOTE_G1,   NOTE_A1s,  NOTE_C2,   NOTE_D2s,  NOTE_G2  },   // Escala Arpegio Men7      I-IIb-V-VIIb-I'-IIIb'-V'
                                {NOTE_C1,  NOTE_D1,   NOTE_E1,   NOTE_G1,   NOTE_A1,   NOTE_C2,   NOTE_D2  },   // Escala Pentatonico Mayor I-II-III-V-VI-I'-II'
                                {NOTE_D1s, NOTE_F1,   NOTE_F1,   NOTE_G1,   NOTE_A1s,  NOTE_C2,   NOTE_D2s }
};  // Escala Pentatonico Menor I-IIIb-IV-VIIb-I'-IIIb'
//------------------------------------------------------------------------------------------------------------------------------------------
int PZ_THR[PZ_Q]  =             {PZ_THR_G, PZ_THR_G,  PZ_THR_G,  PZ_THR_G,  PZ_THR_G,  PZ_THR_G,  PZ_THR_G };   // PZ_Pad Threhold Values (Stablishes the minimum value fr trigger)
int PZ_CTRL[PZ_Q] =             {0,        0,         0,         0,         0,         0,         0        };   // PZ_Pad Recorded Velocity (Initialized to 0 just for fun)

// -----------------------------------------------------------------------------------------------------------------------------------------
// -----------------------------------------------------Control Arrays for POT PAD----------------------------------------------------------
// -----------------------------------------------------------------------------------------------------------------------------------------

// Control Arrays for POT_Pad
//------------------------------------------------------------------------------------------------------------------------------------------
// POT_ID               || POT MIN READ VALUE         || POT_MAX READ VALUE      || Comments
//------------------------------------------------------------------------------------------------------------------------------------------
const int POT_00_ID = 0  ;const int POT_00_MIN =   0  ;int POT_00_MAX = 1024;    // Default Values for potentiometer, change for sensors         
const int POT_01_ID = 1  ;const int POT_01_MIN =   0  ;int POT_01_MAX = 1024;    // Default Values for potentiometer, change for sensors  
const int POT_02_ID = 2  ;const int POT_02_MIN =   0  ;int POT_02_MAX = 1024;    // Default Values for potentiometer, change for sensors
const int POT_03_ID = 3  ;const int POT_03_MIN =   0  ;int POT_03_MAX = 1024;    // Default Values for potentiometer, change for sensors

// SW Control General Parameters
// -----------------------------------------------------------------------------------------------------------------------------------------
const int  POT_Q       =     2;      // POT_Q Number of present SW Pad (Big or Small)
int  POT_CTRL[POT_Q];                // POT_Pad Global Control Array (Initialized to OFF in Setup)
const int  GEN_POT_THR =   100;    // GEN_POT_THR Threshold for Potentiometer No Action

// -----------------------------------------------------------------------------------------------------------------------------------------
// -----------------------------------------------------Control Arrays for JOY PAD----------------------------------------------------------
// -----------------------------------------------------------------------------------------------------------------------------------------
// SW Control General Parameters
// -----------------------------------------------------------------------------------------------------------------------------------------
const int  JOY_Q       =     1;      // POT_Q Number of present SW Pad (Big or Small)
int  JOY_CTRL[2];                // POT_Pad Global Control Array (Initialized to OFF in Setup)

// -----------------------------------------------------------------------------------------------------------------------------------------
// ---------------------------------------------------Control Arrays for MISCELLANIA--------------------------------------------------------
// -----------------------------------------------------------------------------------------------------------------------------------------
// Pin Definition
const int LED          =   2;
const int MUX_A        =   3;
const int MUX_B        =   4;
const int MUX_C        =   5;
const int MUX_D        =   6;
const int MUX_0        =   0;
const int JOY_SW       =   7;
const int JOY_X        =   2;
const int JOY_Y        =   1;
// Constant Values Definition
const bool ON          =   1;         // General ON value
const bool OFF         =   0;         // General OFF value
int        muxSel[4] = {MUX_D, MUX_C, MUX_B, MUX_A}; // MUX Selector Pins
const int  MAX_MIDI_VEL = 127;
// MIDI Global Variables
int       GEN_OCT = 3;     // Global OCTAVE (Make sure initial value is within MIN and MAX)
const int OCT_MIN = 0;    // OCTAVE Min Value
const int OCT_MAX = 6;    // OCTAVE Max Value
int       GEN_SCL = 0;    // Global SCALE (Make sure initial value is within MIN and MAX)
const int SCL_MIN = 0;    // SCALE Min Value
const int SCL_MAX = 5;    // SCALE Max Value
int       GEN_CHN = 0;    // Global CHANNEL (Make sure initial value is within MIN and MAX)
const int CHN_MIN = 0;    // CHANNEL Min Value
const int CHN_MAX = 5;    // CHANNEL Max Value

Adafruit_NeoPixel ledPadStripe = Adafruit_NeoPixel((SW_Q+1), LED, NEO_RGB + NEO_KHZ800);

void setup() {
  Serial.begin(115200);   // Baudrate Set
  ledPadStripe.begin();
  ledPadStripe.show();

  // Set Pin Modes
  pinMode(MUX_A, OUTPUT);
  pinMode(MUX_B, OUTPUT);
  pinMode(MUX_C, OUTPUT);
  pinMode(MUX_D, OUTPUT);
  pinMode(JOY_SW, INPUT);

  // Control Arrays Initialization
  for(int i = 0; i < SW_Q; i++){SW_CTRL[i] = 0;}
  for(int i = 0; i < POT_Q; i++){POT_CTRL[i] = 0;}
  for(int i = 0; i < 1; i++){JOY_CTRL[i] = 0;}
  
  //SW_LED_Initialization();
}

void loop() {
  //GEN_SCL = SW_Read_Iterator(SW_01_INIT, GEN_SCL, SCL_MIN, SCL_MAX, GEN_CHN, SW_01_R_ON, SW_01_G_ON, SW_01_B_ON, GEN_R_OFF, GEN_G_OFF, GEN_B_OFF, FADESTEPS_Q, FADEDELAY_Q);
  //GEN_CHN = SW_Read_Iterator(SW_00_INIT, GEN_CHN, OCT_MIN, OCT_MAX, GEN_CHN, SW_00_R_ON, SW_00_G_ON, SW_00_B_ON, GEN_R_OFF, GEN_G_OFF, GEN_B_OFF, FADESTEPS_Q, FADEDELAY_Q);
  POT_Read_Scale(POT_03_ID, GEN_CHN, GEN_OCT, GEN_SCL, 480, 580, 0);
  //POT_Read_Control(POT_01_ID, GEN_CHN, CTRL_MOD, 0, 1024, GEN_POT_THR);
  //PZ_PAD_Read(GEN_CHN, GEN_OCT, GEN_SCL);
  //JOYSTICK_Read_Scale(GEN_CHN, GEN_SCL, GEN_OCT, GEN_CHN+1, GEN_SCL, GEN_OCT);
}

void PZ_PAD_Read(int CHANNEL, int OCTAVE, int SCALE){
  for (int i = 0; i < PZ_Q; i++) {
    SET_MUXGATE(7-i);
    if (analogRead(MUX_0) > PZ_THR) {
      if (!PZ_CTRL[i]) { // If PZ not activated
        PZ_CTRL[i] = ON;
        // MIDI USB MSSG
        MIDI_TX(CHANNEL,PZ_MIDI_BYTE_1[0][i],(PZ_MIDI_BYTE_2[SCALE][i]+(OCTAVE*12)), map(analogRead(MUX_0),PZ_THR,1024,80,127));
        delay(50);
      }
    }else{
      if (PZ_CTRL[i]) { // If PZ activated
        PZ_CTRL[i] = OFF;
        // MIDI USB MSSG
        MIDI_TX(CHANNEL,PZ_MIDI_BYTE_1[1][i], (PZ_MIDI_BYTE_2[SCALE][i]+(OCTAVE*12)), 0);
      }
    }
  }
}

void SW_Read_Note(int SW_ID, int CHANNEL, byte MIDI_NOTE, int R_ON, int G_ON, int B_ON, int R_OFF, int G_OFF, int B_OFF, int fadeSteps, int fadeDelay){
  SET_MUXGATE(3-SW_ID);
  if (analogRead(MUX_0) < SW_THR){      // If SW Pad activated
    if (!SW_CTRL[SW_ID]){                   // if SW Pad not previously activated
      SW_CTRL[SW_ID] = ON;                   // Set SW_Pad as ON
      MIDI_TX(CHANNEL, NOTE_ON, MIDI_NOTE, 127);
      SW_LED_FadeSingleLoop((SW_ID+1), R_OFF, G_OFF, B_OFF, R_ON, G_ON, B_ON, fadeSteps, fadeDelay);
    }
  }else{
    if(SW_CTRL[SW_ID]){
      SW_CTRL[SW_ID] = OFF;
      MIDI_TX(CHANNEL, NOTE_ON, MIDI_NOTE, 0);
      SW_LED_FadeSingleLoop((SW_ID+1), R_ON, G_ON, B_ON, R_OFF, G_OFF, B_OFF, fadeSteps, fadeDelay);     
   }
  }    // Set SW_Pad as OFF
}

int SW_Read_Iterator(int SW_ID, int ITE, int ITE_MIN, int ITE_MAX, int CHANNEL, int R_ON, int G_ON, int B_ON, int R_OFF, int G_OFF, int B_OFF, int fadeSteps, int fadeDelay){
  SET_MUXGATE(3-SW_ID);
  if (analogRead(MUX_0) < SW_THR){        // If SW Pad activated
    if (!SW_CTRL[SW_ID]){                 // if SW Pad not previously activated
      SW_CTRL[SW_ID] = ON;                // Set SW_Pad as ON
      if (ITE < ITE_MAX){ITE++;}          // Variable Iteration
      else{ITE = ITE_MIN;}
      SW_LED_FadeSingleLoop((SW_ID+1), R_OFF, G_OFF, B_OFF, R_ON, G_ON, B_ON, fadeSteps, fadeDelay);
      MIDIOFF_FIX(CHANNEL, 0, 127);
      delay(200);
    }     
  }else{
    if (SW_CTRL[SW_ID]){
      SW_CTRL[SW_ID] = OFF;                // Set SW_Pad as OFF
      delay(100);
      SW_LED_FadeSingleLoop((SW_ID+1), R_ON, G_ON, B_ON, R_OFF, G_OFF, B_OFF, fadeSteps, fadeDelay);  
    }
  }
  return ITE;
}

void POT_Read_Control(int POT_ID, byte CONTROL_ID, int CHANNEL, int POT_MAX, int POT_MIN, int POT_THR){
  SET_MUXGATE((7-POT_ID));                                                     // POT Positions are mappe in MUX Positions 7 to 4
  if (analogRead(MUX_0) > POT_THR){
    int MUX_READ = map(analogRead(MUX_0),(POT_MIN+POT_THR),POT_MAX,0,127); // Map the value in the MIDI Range [0:127]
    if(MUX_READ != POT_CTRL[POT_ID]){                                            // Do not resend a MIDI if value has not change
      POT_CTRL[POT_ID] = MUX_READ;                                               // State new value in the POT_CTRL
      MIDI_TX(CHANNEL, CONTROL, CONTROL_ID, MUX_READ);                                   // MIDI Control MESSAGE Send
    }
  }
}

void POT_Read_Scale(int POT_ID, int CHANNEL, int OCTAVE, int SCALE, int POT_MAX, int POT_MIN, int POT_THR){
  SET_MUXGATE((7-POT_ID));                                                     // POT Positions are mappe in MUX Positions 7 to 4
  if (analogRead(MUX_0) > POT_THR){
    int MUX_READ = map(analogRead(MUX_0),(POT_MIN+POT_THR),POT_MAX,0,6); // Map the value in the MIDI Range [0:127]
    if(MUX_READ != POT_CTRL[POT_ID]){                                            // Do not resend a MIDI if value has not change
      MIDI_TX(CHANNEL,NOTE_OFF, (PZ_MIDI_BYTE_2[SCALE][POT_CTRL[POT_ID]]+(OCTAVE*12)), 0); // Turn OFF Previous Note
      POT_CTRL[POT_ID] = MUX_READ;                                               // State new value in the POT_CTRL
      MIDI_TX(CHANNEL,NOTE_ON,(PZ_MIDI_BYTE_2[SCALE][POT_CTRL[POT_ID]]+(OCTAVE*12)), 127); // Play New Note
    }
  }else{ // TODO Bad Temporal FIX
    if(POT_CTRL[POT_ID] != 7){
      MIDI_TX(CHANNEL,NOTE_OFF, (PZ_MIDI_BYTE_2[SCALE][POT_CTRL[POT_ID]]+(OCTAVE*12)), 0); // Turn OFF Previous Note
      POT_CTRL[POT_ID] = 7;
    }
  }
}
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

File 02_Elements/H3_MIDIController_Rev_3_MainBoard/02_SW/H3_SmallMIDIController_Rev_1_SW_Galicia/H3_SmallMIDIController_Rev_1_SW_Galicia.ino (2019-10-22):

// Name: H3_MIDIController_Rev_3_SW_Reduced_00
// Programmer: Pablo dMM (Pablodmm.isp@gmail.com)
// Date: October 2018
// Description: Code for H3_MIDIController_Rev_3_Reduced_00 for Test issues. Part of the Henar 3 project in which Autofabricantes collaborates.

// Library Import
#include <Adafruit_NeoPixel.h>
#include <MIDIUSB.h>
#include <Streaming.h>
#include <EEPROM.h>
// Header Custom Files
#include "H3_Configuration.h"
#include "EEPROMAnything.h"

Adafruit_NeoPixel ledPadStripe = Adafruit_NeoPixel(SW_Q, LED, NEO_RGB + NEO_KHZ800);

int ITER = 0;
  int R = 0;
  int G = 50;
  int B = 25;

void setup() {
  Serial.begin(115200);   // Baudrate Set
  ledPadStripe.begin();
  ledPadStripe.show();

  // Set Pin Modes
  pinMode(MUX_A, OUTPUT);
  pinMode(MUX_B, OUTPUT);
  pinMode(MUX_C, OUTPUT);
  pinMode(MUX_D, OUTPUT);

  // Param Initialization

  // LED Start Routine
  SW_LED_Initialization_Start();
  //SW_LED_Initialization_End();
  
  // Param Initialization
  Velocity = map(SW_VEL, 0, 4, 10, 127);

  /*SW_LED_ColumnFade(SW_ROW_CD, SW_MODE, 0, MODE_ON, GEN_OFF, FADESTEPS_C, FADEDELAY_C);
  SW_LED_ColumnFade(SW_ROW_A, SW_INSTR, 0, INSTR_ON, GEN_OFF, FADESTEPS_C, FADEDELAY_C);
  SW_LED_ColumnFade(SW_ROW_BShort, SW_SCALE, 0, MAJOR_ON, GEN_OFF, FADESTEPS_C, FADEDELAY_C);
  SW_LED_ColumnFade(SW_ROW_BShort, SW_SCALE, 0, MAJOR_ON, GEN_OFF, FADESTEPS_C, FADEDELAY_C);
  SW_LED_FadeSingle_UP(SWB0, MINOR_ON, GEN_OFF, FADESTEPS_C, FADEDELAY_C);
  SW_LED_FadeSingle_DW(SWB0, MAJOR_ON, MINOR_ON, FADESTEPS_C, FADEDELAY_C);*/


}

void loop() {

  SWA0 = readSW_Single(SWA0, A0_ON, GEN_OFF, FADESTEPS_C, FADEDELAY_C);
  SWA1 = readSW_Single(SWA1, A1_ON, GEN_OFF, FADESTEPS_C, FADEDELAY_C);
  SWA2 = readSW_Single(SWA2, A2_ON, GEN_OFF, FADESTEPS_C, FADEDELAY_C);
  SWA3 = readSW_Single(SWA3, A3_ON, GEN_OFF, FADESTEPS_C, FADEDELAY_C);

  if(R < 100){R++;}else{R=0;}
  if(G < 100){G++;}else{G=0;}
  if(B < 100){B++;}else{B=0;}
  ledPadStripe.setPixelColor(0, G, R, B);
  ledPadStripe.show(); // Update LEDs
  delay(FADEDELAY_C);
  
}

int readSW_ROW(SWPAD SW_ROW[], int arraySize, int SW_CTRL, LEDCOL COL_ON, LEDCOL COL_OFF, int fadeSteps, int fadeDelay){ // Should Remove arraySize somehow
  int prevON = SW_CTRL;
  for(int i = 0; i < arraySize; i++){ 
     SET_MUXGATE(SW_ROW[i].muxPos);
     if (!digitalRead(SW_ROW[i].muxID)){    // If SW Pad activated // TODO Change to digitalRead()
       if (!SW_ROW[i].swAct){                      // if SW Pad not previously activated
          SW_CTRL = i;                      // Set SW_MODE to that value
          SW_LED_ColumnFade(SW_ROW, SW_CTRL, prevON, COL_ON, COL_OFF, FADESTEPS_C, FADEDELAY_C); // Update LED Stripe
          SW_ROW[i].swAct = ON;                   // Set SW_Pad as ON
if(SW_SDBG){ 
          Serial << "SWPAD ON: " << SW_ROW[i].swID << " MUX GATE: " << SW_ROW[i].muxPos << " LED: " << SW_ROW[i].ledPos << " PAD: " << i << endl;
}else{
          MIDI_TX(SW_INSTR, NOTE_ON, (PZ_MIDI_BYTE_2[SW_SCALE + (3*SW_SCALE_M)][0] + SW_MODE+(12*SW_OCTV)), (Velocity-((Velocity/2)*SW_VSWAP)));
          delay(NOTE_DURATION);
          MIDI_TX(SW_INSTR, NOTE_OFF, (PZ_MIDI_BYTE_2[SW_SCALE + (3*SW_SCALE_M)][0] + SW_MODE+(12*SW_OCTV)), 0);
}
        }
     }else{
       if (SW_ROW[i].swAct){                      // if SW Pad previously activated
         SW_ROW[i].swAct = OFF;                   // Set SW_Pad as ON
       }
     }
  }
   return SW_CTRL;
}

SWPAD readSW_Single(SWPAD SW_Pad, LEDCOL COL_ON, LEDCOL COL_OFF, int FS, int FD){ // Should Remove arraySize somehow
  SET_MUXGATE(SW_Pad.muxPos);
  if (analogRead(SW_Pad.muxID) > 512){    // If SW Pad activated // TODO Change to digitalRead()
   if (!SW_Pad.swAct){                      // if SW Pad not previously activated
      SW_Pad.swAct = ON;                   // Set SW_Pad as ON
if(SW_SDBG){ 
      Serial << "SWPAD ON: " << SW_Pad.swID << " MUX GATE: " << SW_Pad.muxPos << " LED: " << SW_Pad.ledPos << endl;
}
      SW_LED_FadeSingle_UP(SW_Pad, COL_ON, COL_OFF,  FS, FD); // Update LED Stripe
    }
  }else{
   if (SW_Pad.swAct){                      // if SW Pad previously activated
     SW_Pad.swAct = OFF;                   // Set SW_Pad as ON
     SW_LED_FadeSingle_DW(SW_Pad, COL_ON, COL_OFF,  FS, FD); // Update LED Stripe
   }
  }
   return SW_Pad;
}

int readSW_ROW_INSTR(SWPAD SW_ROW[], int arraySize, int SW_CTRL, LEDCOL COL_ON[], LEDCOL COL_OFF, int FS, int FD){ // Should Remove arraySize somehow
  int prevON = SW_CTRL;
  bool instrSel = OFF;
  for(int i = 0; i < arraySize; i++){ 
    ledPadStripe.setPixelColor(SW_ROW[i].ledPos, COL_ON[i].green, COL_ON[i].red, COL_ON[i].blue);
    ledPadStripe.show(); // Update LEDs
    delay(FD);
  }

  while(!instrSel){
   for(int i = 0; i < arraySize; i++){ 
     SET_MUXGATE(SW_ROW[i].muxPos);
     if (!digitalRead(SW_ROW[i].muxID)){    // If SW Pad activated // TODO Change to digitalRead()
       instrSel = ON;
       SW_CTRL = i;                      // Set SW_MODE to that value
        }
     }
  }

  for(int i = 0; i < arraySize; i++){ 
    ledPadStripe.setPixelColor(SW_ROW[i].ledPos, COL_ON[SW_CTRL].green, COL_ON[SW_CTRL].red, COL_ON[SW_CTRL].blue);
    ledPadStripe.show(); // Update LEDs
  }

  delay(FD*FS);

  for(int i = 0; i < arraySize; i++){ 
    ledPadStripe.setPixelColor(SW_ROW[i].ledPos, COL_OFF.green, COL_OFF.red, COL_OFF.blue);
    ledPadStripe.show(); // Update LEDs
  }
  
  return SW_CTRL;
}

int readSW_Binary(SWPAD SW_Pad, int SW_CTRL, LEDCOL COL_ON, LEDCOL COL_OFF, int FS, int FD){ // Should Remove arraySize somehow
  SET_MUXGATE(SW_Pad.muxPos);
  if (!digitalRead(SW_Pad.muxID)){     // If SW Pad activated
   if (!SW_CTRL){                      // if SW_CTRL is OFF
      SW_CTRL = ON;                    // Set SW_Pad as ON
      SW_LED_FadeSingle_UP(SW_Pad, COL_ON, COL_OFF,  FS, FD); // Update LED Stripe
if(SW_SDBG){ 
      Serial << "SWPAD ON: " << SW_Pad.swID << " MUX GATE: " << SW_Pad.muxPos << " LED: " << SW_Pad.ledPos << endl;
      Serial << "Option turned ON" << endl;
}
    }else{
      SW_CTRL = OFF;                    // Set SW_Pad as ON
      SW_LED_FadeSingle_DW(SW_Pad, COL_ON, COL_OFF,  FS, FD); // Update LED Stripe
if(SW_SDBG){ 
      Serial << "SWPAD ON: " << SW_Pad.swID << " MUX GATE: " << SW_Pad.muxPos << " LED: " << SW_Pad.ledPos << endl;
      Serial << "Option turned OFF" << endl;
}
    }
    delay(10);   
  }
   return SW_CTRL;
}
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

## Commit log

2017-12-24 Element Upload 00
    First upload of Element Files of the project, copied from the shared folders in Google Drive.
    [H3_MIDIController_Rev_1_MainBoard.brd, H3_MIDIController_Rev_1_MainBoard.sch, H3_MIDIController_Rev_2_MainBoard (1).brd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]
2018-01-04 General Upload
    Upload fo several items. Part of initial Setup
    [H3_HMI_PulsadorSmall_A_Rev_1.brd, H3_HMI_PulsadorSmall_A_Rev_1.sch, H3_HMI_PulsadorSmall_A_Rev_1_3DRender.skp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]
2018-01-23 More uploads
    Upload of old elements, as part of the repository Setup
    [H3_HMI_PulsadorSmall_A_Rev_1_3DRender.skp, H3_SWPad_Big_Rev_3_3DModel_TOP Esfera.skp, H3_SWPad_Big_Rev_3_PadPiece_Circle.stl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]
2018-07-09 SW Updated
    Added SW_Pad, PZ_Pad, Col, SW_Col as struct.
    First approach to PZ_Pad signal filtering (IIR SW Filter)
2018-07-14 SW Update
    Added:
    - Init LED Sequence
    - PZ Autocalibration and better performance
    Eyh nobody but me reads this :'(
2018-07-22 SW Update -> No PZ_Pads anymore
    This code replaces the PZ_Pads for SW_Pads following the design change due to the 50Hz noise in the Piezos.
    [H3_Configuration.h, H3_MIDIController_Rev_3_SW.ino]
2018-08-01 SW Update
    Changes in the struct of SWPad.
    Minor changes in LED management.
2018-08-02 SW Update
    - Reset Feaure
    - Switch ON timer
    - Instrument selection at init
    - Variety of Aux functions
    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
    [H3_Configuration.h, H3_MIDIController_Rev_3_SW.ino]
2018-08-05 SW Update
    Added Features:
    - EEPROM Save
    - Factory Reset
    - Menu0, Menu1 complete features
    [H3_Configuration.h, H3_MIDIController_Rev_3_SW.ino]
2018-11-05 Updated Reduced_00
    Fixed Reduced_00 reported problems
    [H3_Configuration.h, H3_MIDIController_Rev_3_SW_Reduced_00.ino]
2018-11-10 Reduced Fix
    Fixed Row of MODE (CD2 to CD)
    [H3_Configuration.h, H3_MIDIController_Rev_3_SW_Reduced_00.ino]
2018-11-10 Reduced Fix
    Another Fix of the Reduced Mode
    [H3_MIDIController_Rev_3_SW_Reduced_00.ino]
2019-10-22 Added Velostat Test
    Added small circuit and Arduino Code to test the Velostat new Pads

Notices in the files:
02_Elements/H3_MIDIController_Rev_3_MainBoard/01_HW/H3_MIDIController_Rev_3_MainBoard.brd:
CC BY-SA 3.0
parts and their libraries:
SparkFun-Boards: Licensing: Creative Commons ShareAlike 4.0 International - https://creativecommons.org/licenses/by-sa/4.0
